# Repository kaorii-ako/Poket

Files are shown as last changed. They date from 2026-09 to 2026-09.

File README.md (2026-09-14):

# Poket

A pocket Bluetooth MP3 player built around an ESP32-S3.

Plays MP3s off a microSD card and sends them either to Bluetooth
headphones (A2DP source) or out a 3.5 mm jack.

> **Rev B changed the MCU.** The board started on an ESP32-S3, which turned out
> to have Bluetooth LE only — no BR/EDR — so A2DP could never have worked on it.
> `soc_caps.h` in ESP-IDF spells it out: the S3 defines `SOC_BLE_SUPPORTED` and
> not `SOC_BT_CLASSIC_SUPPORTED`. The classic ESP32 in the WROOM-32E-R2 has
> both, keeps its 2 MB PSRAM inside the chip package (so GPIO16/17 stay free,
> unlike a WROVER), and costs a USB-UART bridge because it has no native USB. 0.96" OLED, rotary
encoder, three transport buttons, LiPo with USB-C charging and a
coulomb-counting fuel gauge.

| | |
|---|---|
| MCU | ESP32-WROOM-32E-N16R2 (16 MB flash, 2 MB in-package PSRAM) |
| Storage | microSD over SPI |
| DAC | PCM5102A (I2S, internal PLL — no MCLK needed) |
| Headphone amp | PAM8908, charge-pump / ground-centred output |
| Charger | MCP73831, 500 mA, P-FET load share |
| Fuel gauge | BQ27441-G1 with 10 mΩ sense resistor |
| Rail | AP2112K-3.3, separate ferrite-isolated 3V3A for the audio |
| USB | CP2102N-A02 bridge + cross-coupled auto-reset (this part has no native USB) |
| Board | 80 × 54 mm, 4 layer (Sig / solid GND / Sig / Sig) |
| Case | 86 × 60 × 16.8 mm, 3D printed, two shells + slider cap, chamfered edges |

## The board

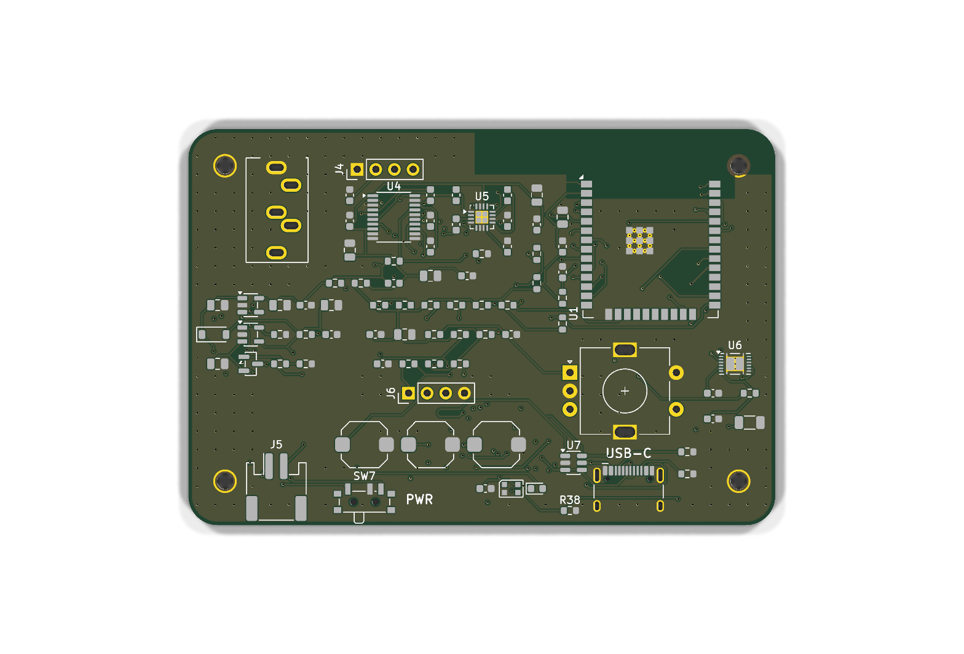
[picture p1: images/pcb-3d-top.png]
PCB top


Top side: ESP32-S3 module and its antenna keepout top-right, audio chain and
power block under where the OLED sits, encoder centre-right, three transport
buttons along the bottom, USB-C bottom-right, 3.5 mm jack top-left.

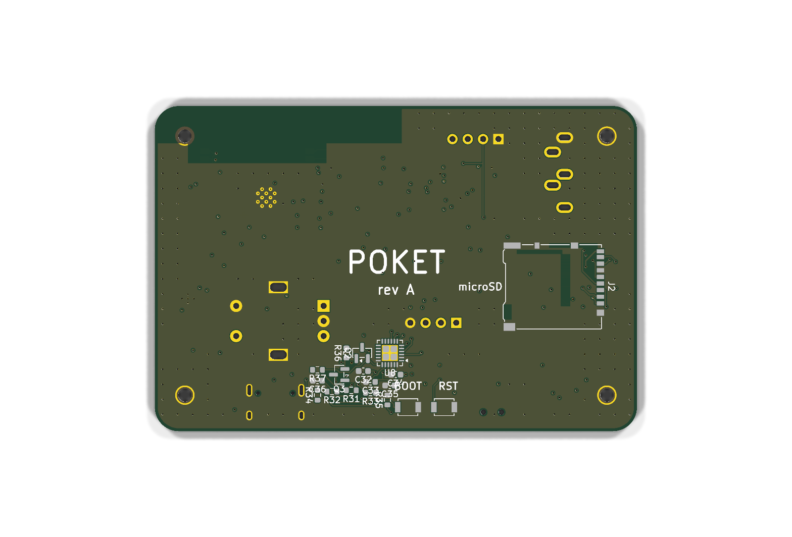
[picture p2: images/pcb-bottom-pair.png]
PCB bottom


Bottom side carries the microSD socket and the BOOT/RESET buttons, so the top
face stays clean. Right: all four copper layers together — In1.Cu is a solid
ground plane with no signal on it at all.

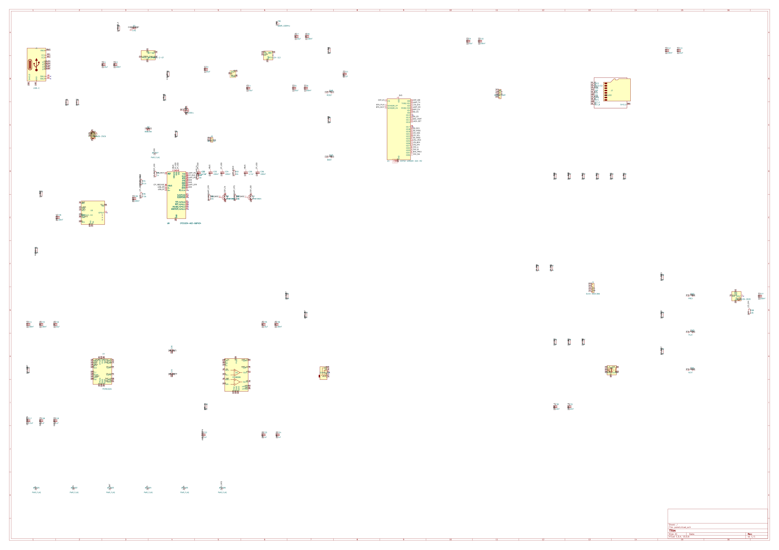
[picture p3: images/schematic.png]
schematic


Full schematic (also as a PDF: [`docs/poket-schematic.pdf`](docs/poket-schematic.pdf)).
ERC clean — 0 errors, 0 warnings.

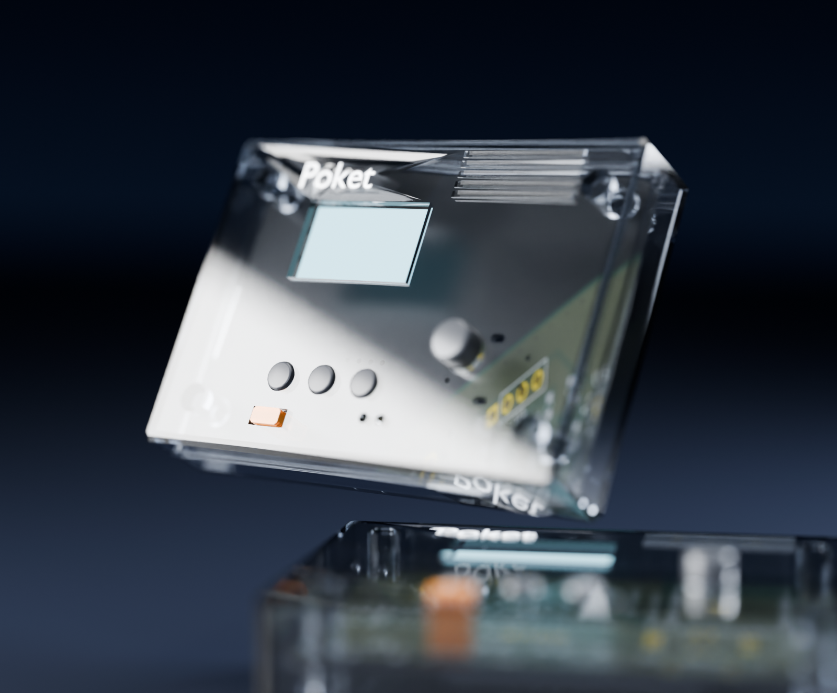
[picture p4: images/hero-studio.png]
case


## The firmware

ESP-IDF v5.3, C. Reads MP3s off the card with a vendored [minimp3], decodes
into PSRAM and pushes PCM to either sink — I2S to the PCM5102A, or A2DP source
to a paired pair of headphones.

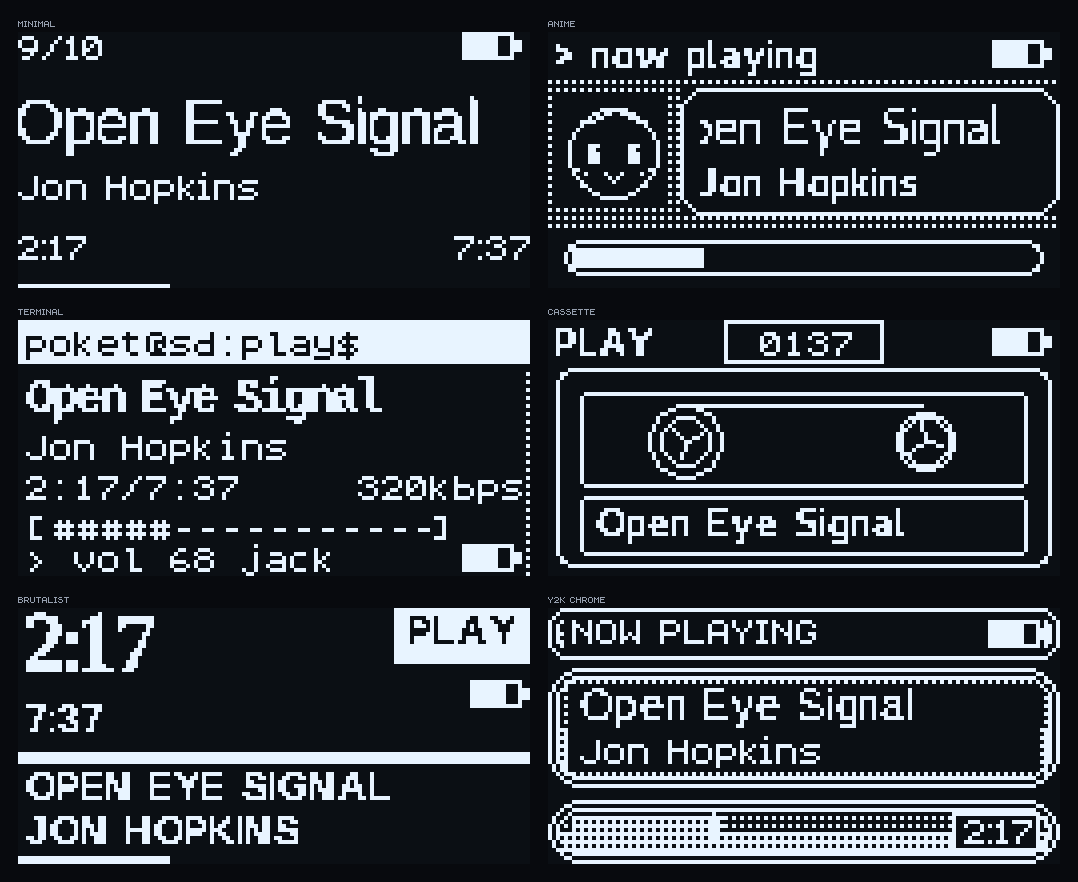
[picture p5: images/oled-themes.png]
OLED themes


Six themes ship, and they are not palette swaps — a 1-bit 128 x 64 panel has no
colour to vary, so each one earns its difference through layout, typeface,
iconography and motion. Clockwise from top-left: **Minimal**, **Anime**
(a face that blinks on its own timer), **Cassette** (reels that wind across as
the track plays), **Y2K Chrome**, **Brutalist**, **Terminal**. A seventh slot
takes a custom theme uploaded from the browser; that one is *data*, not code,
so an uploaded pack can lay out screens but can never execute on the device.

The two smallest faces are a hand-drawn 5x8 bitmap table
([`tools/font5x8.py`](firmware/tools/font5x8.py)) — rasterising an outline at
7-8 px loses whole stems, and a 1-bit panel has no antialiasing to hide that
with. The rest come from real faces through
[`tools/mkfont.py`](firmware/tools/mkfont.py).

### Build and flash

ESP-IDF v5.3, target `esp32`. Full detail in
[`firmware/README.md`](firmware/README.md).

```bash
. $HOME/esp/esp-idf/export.sh
cd firmware
idf.py set-target esp32          # once
idf.py build
idf.py -p /dev/ttyUSB0 flash monitor
```

`sdkconfig.defaults` carries the flash size, PSRAM, Classic Bluetooth and the
partition table, so a clean tree builds without menuconfig. The CP2102N bridge
handles reset and boot mode, so flashing needs no button presses; if auto-reset
ever fails, hold **BOOT**, tap **RESET**, release **BOOT**.

Then: put MP3s in `/Music` on a FAT32 card, power on, long-press the encoder,
join the `Poket-XXXX` network shown on screen and open **http://192.168.4.1**.

### The web app

Hold the encoder and Poket brings up its own Wi-Fi access point and serves a
page: drag MP3s onto it to write them to the card, browse the library, drive
transport, and pick the screen theme with a **live 128 x 64 preview**. The
preview is not an artist's impression — `web/proto/oled.js` is a port of
`ui/gfx.c` and runs the same theme code against the same generated glyph bytes,
painted at an integer zoom so one panel pixel is exactly N x N screen pixels
with smoothing off.

Four design directions are prototyped in
[`firmware/web/proto/`](firmware/web/proto/) — open `index.html`:

| | |
|---|---|
| `jcard.html` | ink on cassette card stock; upload zone is a blank Side B |
| `bench.html` | desk instrument — keycaps with travel, knurled knob, amber readout |
| `fab.html` | the board documenting itself: silkscreen on solder mask, designators, title block |
| `plain.html` | the canon settings page; the control the other three have to beat |

Wi-Fi and Bluetooth share one radio, so while the page is being served audio
routes out the 3.5 mm jack.

[minimp3]: firmware/components/minimp3/

## Video

| | |
|---|---|
| [`video/poket-promo.mp4`](video/poket-promo.mp4) | 22 s product film — five shots, titles |
| [`video/poket-assembly.mp4`](video/poket-assembly.mp4) | 6.5 s — parts drop in, then a turntable |

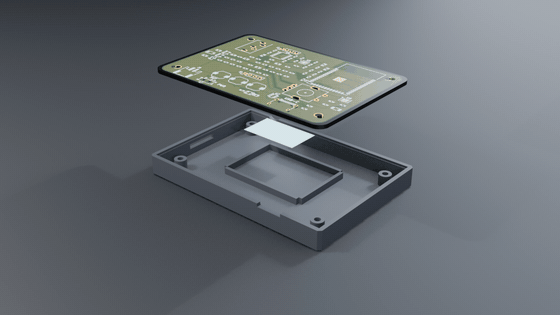
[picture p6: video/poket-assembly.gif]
assembly


Both are rendered from the same Blender scene, which rebuilds from scratch
with `blender/build_scene.py` (set `MODE` to `"promo"` or `"assembly"`).
Encode the PNG sequences with `tools/encode_video.sh`.

## Documentation

- [`docs/BOM.md`](docs/BOM.md) — bill of materials, ~$46/unit
- [`docs/ASSEMBLY.md`](docs/ASSEMBLY.md) — how to build one
- [`docs/DESIGN.md`](docs/DESIGN.md) — why each part was chosen, and the trade-offs
- [`docs/SUBMISSION.md`](docs/SUBMISSION.md) — what's done, what isn't
- [`JOURNAL.md`](JOURNAL.md) — build log

## Repo layout

```
poket.kicad_sch / .kicad_pcb / .kicad_pro   KiCad 10 project
firmware/                                   ESP-IDF app - drivers, audio, UI themes, web app
cad/enclosure.py                            parametric enclosure (FreeCAD, headless)
enclosure/*.step, *.stl                     exported case parts
docs/                                       BOM, assembly, design notes, schematic PDF
fab/                                        gerbers, drill, pick-and-place
images/                                     renders and screenshots
blender/                                    animation scene + board textures
video/                                      promo + assembly animations
tools/                                      fab export, video encode, PCB helper scripts
JOURNAL.md                                  build log
```

## Building the enclosure model

```
flatpak run --filesystem=host --command=FreeCADCmd org.freecad.FreeCAD cad/enclosure.py
```

Everything is driven by the constants at the top of `cad/enclosure.py`, so
if the PCB outline or a connector moves, change the number and re-run.

## Print settings

PETG or PLA, 0.2 mm layers, 4 perimeters, 20 % infill, no supports needed.
Front shell prints face-down, back shell prints tray-up. 4 × M2 heat-set
inserts (3.2 mm OD) in the front shell bosses; 4 × M2 × 12 screws from the
back.

## Status

**Hardware** — ERC **0 errors, 0 warnings**; DRC **0 errors, 0 schematic-parity
issues**, every signal net routed. The enclosure booleans against the real board
STEP with **0.0000 mm³** interference. Gerbers, drill and pick-and-place in
`fab/` are generated from this revision.

**Firmware** — complete and building. ESP-IDF v5.3, `idf.py build` succeeds from
a clean tree; `poket.bin` is 1.5 MB with 64 % of the app partition free. Drivers,
the audio path with A2DP linking, microSD over SPI, the library scanner, `.m3u`
playlists, the 1-bit graphics layer with six themes, the Wi-Fi access point, the
HTTP server and the web app are all in `firmware/`. Build and flash instructions:
[`firmware/README.md`](firmware/README.md).

**Not built.** No board has been fabricated, no part soldered, and no firmware
has ever run on hardware. Every image here is a render. The design is verified
in software and the firmware compiles — but "passes DRC and builds" and "works"
are different claims, and only the first is being made. Full gap list:
[`docs/SUBMISSION.md`](docs/SUBMISSION.md).

Three ground-pour fragments are untied, two of which carry a bypass capacitor's
ground. Documented rather than hidden.

## Design review

> **Not yet reviewed by another person.** This needs a second pair of eyes
> before fabrication, and nobody has given it one yet.
>
> When someone does, record it here: who reviewed it, when, what they flagged,
> and what changed as a result. An unreviewed board is a board with exactly one
> person's blind spots in it — and this project has already had one part choice
> that a reviewer would very likely have caught (the ESP32-S3 cannot do A2DP,
> which is the whole point of the device).

Worth a reviewer's attention in particular:

- **Power** — the MCP73831 charger, the DMG2301L load-share P-FET and the
  AP2112K rail, especially behaviour when USB and battery are both present.
- **The CP2102N block** — the 22.1 k/47.5 k VBUS sense divider and the
  cross-coupled auto-reset pair (`Q2` drives EN, `Q3` drives IO0, emitters
  cross). Both came from datasheets rather than from a copied schematic.
- **Strapping pins** — GPIO0, 2, 12 and 15. GPIO12 is deliberately left
  unconnected and the microSD runs on SPI to keep off it.
- **The antenna keepout** and whether the module is close enough to the board
  edge to radiate properly.

## License

MIT for code, CERN-OHL-S v2 for the hardware design files. See [`LICENSE`](LICENSE).

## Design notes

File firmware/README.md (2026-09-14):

# Poket firmware

ESP-IDF v5.3, target `esp32` (ESP32-WROOM-32E-N16R2).

```
main/
  main.c            bring-up order: NVS, panel, card, audio
  board.h           the pin map, extracted from the schematic netlist
  app/              the one shared state snapshot + the UI task
  drivers/          I2C, SSD1306, encoder + buttons, BQ27441 fuel gauge
  storage/          microSD over SPI, library scan, ID3, .m3u playlists
  audio/            minimp3 -> one sink interface -> I2S or A2DP
  ui/               1-bit graphics, six themes, font tables
  net/              Wi-Fi AP, HTTP server, the gzipped web app
web/                the web app source; build.py bundles it into net/www.h
tools/              font generation
```

## Build

Install ESP-IDF v5.3, then:

```bash
. $HOME/esp/esp-idf/export.sh      # wherever you installed it
cd firmware
idf.py set-target esp32            # only needed once
idf.py build
```

`sdkconfig.defaults` already carries everything that matters — 16 MB flash,
PSRAM, Classic Bluetooth with A2DP, the custom partition table — so a clean
tree builds without touching menuconfig.

Expect roughly:

```
poket.bin binary size 0x1741d0 bytes. Smallest app partition is 0x400000 bytes.
```

## Flash

The board has no native USB — a CP2102N bridge sits on UART0, with the usual
cross-coupled auto-reset pair — so flashing works without touching any buttons.

```bash
idf.py -p /dev/ttyUSB0 flash monitor
```

On Linux the port is usually `/dev/ttyUSB0`, on macOS
`/dev/cu.SLAB_USBtoUART`, on Windows a `COM` port. `idf.py -p PORT monitor`
alone opens the serial log; Ctrl-] exits.

If auto-reset ever fails, hold **BOOT**, tap **RESET**, release **BOOT**, and
flash again. Both buttons are on the back of the board.

Erasing everything, including the saved Wi-Fi password, theme choice and
remembered headset:

```bash
idf.py -p /dev/ttyUSB0 erase-flash
```

### Flashing prebuilt binaries

Without ESP-IDF installed, `esptool` is enough:

```bash
esptool.py --chip esp32 -p /dev/ttyUSB0 -b 460800 \
  --before default_reset --after hard_reset write_flash \
  --flash_mode dio --flash_size 16MB --flash_freq 80m \
  0x1000 build/bootloader/bootloader.bin \
  0x8000 build/partition_table/partition-table.bin \
  0x10000 build/poket.bin
```

## First run

1. Put MP3s in `/Music` on a FAT32 microSD card and insert it.
2. Power on. The splash shows while the library is scanned.
3. **Long-press the encoder** to start transfer mode. The screen shows the
   Wi-Fi name (`Poket-XXXX`) and its password — generated on first boot and
   kept in NVS, so it does not change.
4. Join that network and open **http://192.168.4.1**.

From the web app: drop MP3s in, search the library, make playlists, drive
transport, pick one of the six screen themes with a live preview, and link a
pair of Bluetooth headphones.

### Linking headphones

Poket is the A2DP **source**, so it goes looking rather than waiting to be
found. Put the headphones in pairing mode, hit **Scan for headphones**, and pick
them from the list. The headset is saved and reconnected automatically on later
boots. **Long-press Play** toggles between the jack and Bluetooth.

Wi-Fi and Bluetooth share one radio, so audio can stutter while the web app is
open. In normal use it is one or the other.

## Controls

| Input | Action |
|---|---|
| Encoder turn | volume, or move the selection in the browser |
| Encoder press | browser / now playing |
| Encoder long-press | start or stop transfer mode |
| Play | play / pause |
| Play long-press | switch between the jack and Bluetooth |
| Prev / Next | previous (restarts if >3 s in) / next |

## Regenerating the generated files

Both are checked in, so neither is needed for an ordinary build.

```bash
cd tools && ./genfonts.sh     # main/ui/fonts_gen.c and web/lib/fonts.js
cd web    && ./build.py       # bundles the web app into main/net/www.h
```

The web app is inlined and gzipped into rodata because the access point has no
route to the internet: a single external `<script>` would leave the page blank.
`build.py` fails the build if the bundle exceeds 60 kB gzipped, or if two
modules declare the same top-level name.

```bash
node web/lib/clock.test.mjs   # playback-position arithmetic
```

## Known gaps

Nothing here has run on real hardware — no board has been fabricated. It builds
and the logic follows Espressif's reference implementations, but it has never
played a note. See [`../docs/SUBMISSION.md`](../docs/SUBMISSION.md).

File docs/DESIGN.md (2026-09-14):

# Poket — design decisions and trade-offs

## What it is

An ESP32 Bluetooth MP3 player. Local MP3s on a microSD card, played
out either over Bluetooth A2DP (as a *source*, to headphones/speakers) or
through a wired 3.5 mm jack. 0.96" OLED, rotary encoder with push, three
transport buttons, single-cell LiPo with USB-C charging.

---

## Electrical

### MCU — ESP32-WROOM-32E-N16R2, not a bare chip
The module costs a few dollars more than the bare die plus flash plus
PSRAM, and it saves the antenna matching network, the RF layout review,
and a pile of risk on a first spin. 16 MB flash gives room for the
firmware and a filesystem; 2 MB in-package PSRAM gives the decode buffers you
want if you ever add gapless playback or a bigger UI.

Cost: the octal-PSRAM variant burns GPIO35/36/37 internally, so those are
off-limits. Native USB takes GPIO19/20. Everything else was assigned
around those.

### Audio chain — PCM5102A → PAM8908 → jack
The PCM5102A has an internal PLL, so it runs from BCK/LRCK alone and I
don't have to spend a GPIO and a clock domain on MCLK. Its output is
ground-centred thanks to an on-chip charge pump, which kills the usual
big DC-blocking electrolytics.

It can't drive 32 Ω headphones though (2.1 Vrms into 5 kΩ is a line
output), so the PAM8908 does the current. It's also a DirectDrive-style
charge-pump part — ground-referenced output, no output coupling caps, no
turn-on thump. Gain pins strapped for 0 dB; the amp is enabled from
GPIO21 so firmware can mute it before the DAC settles.

**Trade-off:** the PAM8908 is a QFN-16 with a thermal pad. Not
hand-solder friendly. If this were meant for hand assembly I'd have taken
the TPA6132A2 in the same pinout family, or dropped back to a jellybean
op-amp buffer and accepted the coupling caps.

### Fuel gauge — BQ27441-G1, not the MAX17048 I wanted
The MAX17048 is the nicer part for this job: ModelGauge estimates state of
charge from voltage alone, so there's no sense resistor and no
interruption of the pack ground. But there's no symbol for it in the
stock KiCad libraries and I wasn't confident enough in the TDFN pinout
from memory to draw one — a wrong pin here is a dead board.

The BQ27441-G1 has a verified KiCad symbol, so that's what went in. It's
a real coulomb counter, which is arguably *more* accurate, at the cost of
a 10 mΩ sense resistor in series with the pack negative and a slightly
more careful ground layout (SRP on the battery side, SRN on system
ground).

### Power path
```
USB-C ──┬── USBLC6 ESD ── D+/D- ── CP2102N ── UART0 ── ESP32
        ├── MCP73831 (500 mA) ── VBAT ── LiPo
        └── Schottky ──┐
                       ├── VSYS ── slide switch on LDO EN ── AP2112K-3.3 ── 3V3
   VBAT ── P-FET ──────┘                                                    │
          (off when VBUS present)                                    ferrite ┴ 3V3A
```

Two decisions worth calling out:

**Load-share gate divider.** First pass used 100 k / 100 k from VBUS to
the P-FET gate. That puts the gate at 2.5 V while the source sits at
4.2 V — Vgs = −1.7 V, so the FET is *partially on* and the USB supply
back-feeds the battery through it. Changed to 10 k from VBUS to the gate
and a 1 M pulldown: gate sits at ~5 V with USB in (hard off) and at 0 V
without it (hard on).

**LDO, not a buck-boost.** A TPS63020 would hold 3.3 V down to a 3.0 V
cell and be ~90 % efficient instead of ~80 %. An AP2112K is a $0.10
SOT-23-5 and a basic JLC part. For a first build I took the simple one and
accepted that the usable cell range stops around 3.4 V. The board will
run below that (the ESP32 and both audio parts are happy at 3.0 V),
the rail just isn't regulated any more.

**Analog rail.** 3V3A is split off through a ferrite bead with its own
bulk + bypass, feeding the DAC and amp only. Cheap insurance against the
radio and the SD card putting hash into the audio.

### microSD on SPI, not SPI
Four data lines instead of one, roughly 4× the read bandwidth for the
same clock. MP3 doesn't need it, but it means the card is idle more of
the time, which matters when the radio is also asking for the bus. 10 k
pull-ups on CMD and all four data lines; card detect on the socket's
detect switch.

### Board stackup — 4 layer
Signal / **solid GND** / signal+GND pour / signal+GND pour.

The first autorouting pass came back with 439 mm of signal trace sitting
on In1.Cu, which shreds exactly the plane I added the layer for. Second
pass I marked In1.Cu as `(type power)` in the Specctra DSN so the router
would not touch it — it now carries no signal copper at all, so every
trace on the component side has an uninterrupted return path directly
underneath it. In2.Cu and B.Cu carry the rest of the routing with ground
poured around them.

### The ESP32 antenna keepout
KiCad's `ESP32-WROOM-32E-N16R2` footprint carries a 48 × 21 mm copper keepout
zone for the antenna, applied to every layer, plus a courtyard outline of
the same shape. Both are far more conservative than the module datasheet
needs and they make placement on an 80 × 54 board impossible.

I removed the vendor zone from the board instance, replaced the courtyard
with a plain rectangle around the module body, and shaped all four ground
pours to leave a notch (x 52–74, y 0–9.5 mm) open under and beside the
antenna instead. Same intent, sized to the part.

---

## Mechanical

### Layout logic
The front face is what you look at, so the screen, buttons and knob are
all top-side. Two things went to the *bottom* of the board on purpose:

- **microSD socket** — it's 15 mm deep. On the top side it would have
  eaten a fifth of the usable area; underneath, it tucks into the space
  above the battery and its slot lines up with the left wall.
- **BOOT and RESET** — these are setup buttons, not user controls.
  Pinholes in the back shell instead of two extra holes in the face.

### Case
86 × 60 × 16.8 mm, two shells split 1 mm above the PCB plane.

- **Back shell** is a tray: 1.5 mm floor, four 4.7 mm posts that the PCB
  sits on, and ribs that pen the battery into a 37 × 26 mm pocket so it
  can't slide onto the BOOT/RESET pinholes.
- **Front shell** is the cover, with the display window, three button
  holes, the encoder shaft hole, two LED pinholes, the power-slider slot,
  and five debossed vent slots top-right that are purely decoration.
- **Registration** is a 0.7 mm tongue on the front shell dropping into a
  0.25 mm-clearance rebate in the back shell wall.
- **Fastening** is four M2 × 12 screws from the back, through the posts
  and the PCB, into heat-set inserts in the front shell bosses. One screw
  does all three jobs.

### The slider cap
The power switch is an SMD slide switch whose actuator only stands about
2.5 mm off the PCB, but the front face is 7.5 mm above it — you'd never
reach it. So there's a third printed part: a 6 × 3 × 8.8 mm cap with a
pocket that grips the actuator and thumb grooves on top, poking through a
7.6 mm slot. 1.6 mm of travel, which matches the switch.

### Assumptions
- FDM print, PETG or PLA, 0.2 mm layers, 0.2 mm part clearance
- M2 heat-set inserts, 3.2 mm OD × 4 mm
- 402535-size LiPo (4 × 25 × 35 mm, ~400 mAh) in the battery bay
- 0.96" I2C SSD1306 module, 27.3 × 27.8 mm, on a 4-pin header

---

## Known compromises

1. **Screw near the antenna.** The top-right mounting hole is ~3 mm from
   the module's antenna edge. It's an unplated hole with no copper, but a
   steel M2 screw there isn't ideal. Moving it means an asymmetric screw
   pattern; I took the symmetry.
2. **No MCLK to the DAC.** Fine for the PCM5102A's internal PLL, but it
   rules out swapping in a DAC that needs a master clock without a board
   change.
3. **LDO efficiency.** See above — costs maybe 15 % of runtime versus a
   buck-boost.
4. **Screen is left of centre** on the front face, because the OLED
   module hangs off a header at a fixed spot. Reads as deliberate
   asymmetry (screen left, knob right) rather than a mistake, but it
   wasn't a free choice.
5. **QFN parts.** The amp and the fuel gauge both need reflow or a hot
   plate. This board wants to be assembled, not hand-built.

## Why the MCU changed (Rev A -> Rev B)

Rev A used an ESP32-S3. It cannot do A2DP: the S3 has Bluetooth LE only, no
BR/EDR. ESP-IDF's own capability header says so —

```
soc/esp32/include/soc/soc_caps.h    #define SOC_BT_CLASSIC_SUPPORTED (1)
soc/esp32s3/include/soc/soc_caps.h  #define SOC_BLE_SUPPORTED        (1)   <- only
```

`CONFIG_BT_CLASSIC_ENABLED` is not even a config symbol for that target. Sending
audio to Bluetooth headphones is the entire point of this device, so the part
had to change.

**ESP32-WROOM-32E-N16R2** (ESP32-D0WDR2-V3): Classic BT + BLE, 16 MB flash, and
2 MB of PSRAM *inside the chip package* — so, unlike a WROVER, it costs only
GPIO16 rather than GPIO16 and GPIO17.

What that dragged in:

| Change | Why |
|---|---|
| CP2102N-A02 USB-UART bridge | the classic ESP32 has no native USB |
| 22.1k/47.5k divider on the bridge's VBUS pin | datasheet: abs max on that pin is VIO + 2.5 V |
| 1k pull-up on RSTb to VIO | datasheet value; 10k is not enough |
| 4.7 uF + 0.1 uF at each bridge power pin | datasheet, per pin, not per chip |
| Cross-coupled auto-reset pair | Espressif's DevKitC truth table: asserting DTR and RTS together must *not* reset, because opening a serial port does exactly that |
| microSD moved to SPI | the 4-bit slot puts DAT2 on GPIO12/MTDI, the flash-voltage strap; a card's pull-up there tells the bootloader the flash is 1.8 V and bricks the boot |
| Battery-sense divider deleted | ADC1 is fully used by the encoder and the input-only buttons, ADC2 stops working with Wi-Fi up, and the BQ27441 reports voltage over I2C anyway |
| 10k pull-down on GPIO2 | download-mode strap, and a WS2812 data pin is high-Z |

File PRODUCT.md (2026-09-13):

# Poket — product context

> Written from the maintainer's explicit brief (the four scoping answers on the
> firmware request) rather than a fresh interview. Anything not covered by that
> brief is marked **[assumed]** and should be corrected rather than trusted.

## What it is

A pocket MP3 player built from scratch: custom 4-layer PCB around an
ESP32-S3-WROOM-1, 3D-printed case, microSD library, 0.96" mono OLED, rotary
encoder and three transport buttons. Audio leaves either over Bluetooth A2DP
to headphones or out a 3.5 mm jack.

It is a hardware project first. The web app exists because the device has no
other way to receive files.

## Who uses it

One person: whoever built the unit. There is no fleet, no accounts, no
multi-tenant anything. **[assumed]** they are technically confident — they
soldered a QFN — but are using this on a phone, one-handed, while the device
sits on a desk.

## The web app's job

The device has no keyboard, no file manager, and a 128×64 screen. Everything
that is painful on that screen moves to the browser:

1. **Get MP3s onto the card.** The primary job. Drag, drop, done.
2. **Browse and organise** what is already there; build playlists.
3. **Choose the OLED theme**, with a preview accurate enough to decide from.
4. **Drive playback** from the browser while the device is across the room.
5. **Settings** — Wi-Fi, Bluetooth pairing, sleep, brightness, battery.

## Hard constraints that shape the design

- **Served off an ESP32-S3.** The whole app — markup, styles, script — is
  embedded in flash and gzipped. Budget: **under 60 kB compressed, single
  file, zero network dependencies.** No framework, no CDN font, no icon
  package. This is the constraint that decides the most.
- **Wi-Fi and Bluetooth share one radio.** When the web app is reachable,
  Bluetooth audio is not. Transfer mode and playback mode are genuinely
  exclusive and the UI has to be honest about that rather than hide it.
- **Uploads are slow.** ~1–2 MB/s over the device's own AP. A 60 MB album is
  most of a minute. Progress has to be real, per-file, and resumable in the
  sense that a failure names the file that failed.
- **The device may be on battery.** Long transfers matter; the UI should show
  charge state without being asked.
- **One client at a time, realistically.** No collaboration, no conflict
  resolution, no optimistic concurrency.

## What success looks like

Someone plugs in a fresh card, joins the Poket hotspot, drags a folder of
music in, picks a theme, and unplugs — without reading anything.

## Explicitly out of scope

Accounts, cloud sync, streaming services, transcoding, album art fetching,
mobile apps, OTA firmware from the browser **[assumed]** — the partition table
reserves OTA slots but nothing in the brief asked for browser-driven updates.

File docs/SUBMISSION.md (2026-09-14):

# Submission checklist

## What's in the repo

| Requirement | Where | Status |
|---|---|---|
| Devlog / journal | [`JOURNAL.md`](../JOURNAL.md) | 11 entries, ~34 h, written as the work happened |
| Schematic (source) | `poket.kicad_sch` | KiCad 10, ERC **0 errors, 0 warnings** |
| Schematic (PDF / PNG) | [`docs/poket-schematic.pdf`](poket-schematic.pdf), `images/schematic.png` | regenerated from the Rev B board |
| PCB layout (source) | `poket.kicad_pcb` | DRC **0 errors, 0 schematic-parity issues**, every signal net routed |
| Gerbers + drill | `fab/poket-gerbers.zip` | 4-layer, JLCPCB-ready, Rev B |
| Pick-and-place | `fab/poket-pos.csv` | Rev B |
| BOM with costs | [`docs/BOM.md`](BOM.md), [`docs/BOM.csv`](BOM.csv) | costs are **estimates**; supplier P/Ns not filled in |
| CAD source | `cad/enclosure.py` | parametric, rebuilds from the script |
| Printable files | `enclosure/*.stl` | 3 parts, all single valid solids, 0.0000 mm³ interference vs the board |
| Renders / video | `images/`, `video/` | board renders regenerated for Rev B |
| License | [`LICENSE`](../LICENSE) | MIT (code) + CERN-OHL-S v2 (hardware) |
| Assembly instructions | [`docs/ASSEMBLY.md`](ASSEMBLY.md) | includes the Rev B parts |
| **Firmware** | `firmware/` | **written and building** — ESP-IDF v5.3, `poket.bin` 1.5 MB, 64 % of the app partition free |
| Flashing instructions | [`firmware/README.md`](../firmware/README.md), README | build, flash, first run, controls |
| Design reviewed by another person | — | **not yet done** — see the README's Design review section |
| Photos of real hardware | — | **never built** |

## The firmware

ESP-IDF v5.3, target `esp32`. `idf.py build` succeeds from a clean tree.

- **Audio** — vendored minimp3, one sink interface behind I2S (PCM5102A) and
  A2DP source. Bluetooth linking is implemented properly: inquiry, Class-of-
  Device filter for audio sinks, connect, then `CHECK_SRC_RDY` → `MEDIA_CTRL_START`.
  The headset is remembered in NVS and reconnected at boot.
- **Storage** — microSD over SPI, library scan, ID3 tags, playlists as `.m3u`
  files in `/Music/Playlists` so any other player can read them.
- **UI** — 1-bit graphics layer and six themes that differ in layout, type,
  iconography and motion, because a 1-bit panel has no colour to vary. Custom
  theme packs are interpreted as *data*, never executed.
- **Web app** — served gzipped from rodata, 30 kB, no external requests. Upload,
  library with search, playlists, transport, shuffle/repeat, Bluetooth pairing,
  and a live 128×64 screen preview that runs the firmware's own drawing code
  against the same glyph bytes.

## Honest gaps

**1. Nothing has been physically built.** Every image is a render. No board has
been fabricated, no part soldered, no measurement taken, and no firmware has
ever run on hardware. The design is ERC/DRC-clean, the enclosure is
boolean-verified against the real board outline, and the firmware compiles — but
"it passes DRC and builds" and "it works" are very different claims, and only
the first is being made here.

**2. Three ground-pour fragments are untied.** Two of them carry a bypass
capacitor's ground (C19, C33). The plane itself is intact and every signal net
is routed, but those two caps' ground return is not ideal. The fix is to move
the caps and re-route; noted rather than hidden.

**3. The BOM has no supplier part numbers.** Manufacturer part numbers are real
and chosen deliberately; LCSC/DigiKey numbers are blank rather than guessed.

**4. Prices are estimates**, not quotes. ~$46 is the right order of magnitude.

**5. Nobody else has reviewed it.** A second pair of eyes before fabrication is
the cheapest bug-finding there is, and this design has not had one. The README
lists what a reviewer should look at hardest.

**6. Rev A was wrong about Bluetooth.** The first board used an ESP32-S3, which
has Bluetooth LE only and physically cannot do A2DP. That is documented in
[`DESIGN.md`](DESIGN.md) and in the devlog rather than quietly corrected — it is
the most useful thing I learned building this.

## Is it ready?

As a **design and firmware submission**: yes, with one caveat — it has not been
reviewed by another person, which is worth doing before anyone spends money
having it made.

On the substance: Schematic, layout, fabrication
outputs, enclosure, and a complete firmware source tree that builds, all
consistent with each other and all regenerated from the current revision.

As a **working device**: no, and it does not claim to be. It has never been
built. Everything above describes what the design and the code do, not what a
physical unit has been observed to do.

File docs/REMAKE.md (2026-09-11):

# Shot-for-shot remake of the reference film

`video/poket-remake.mp4` is a beat-for-beat rebuild of the reference phone
launch film, with Poket in place of the phone.

## How the cut list was derived

Not by eye — ffmpeg scene detection on the source:

```
ffmpeg -i reference.mp4 -filter:v "select='gt(scene,0.30)',showinfo" -f null -
```

That gives 16 cuts. The last four shots (34.36 s onward) are a live-action
talking head at a desk. There is no way to reproduce those here, so the remake
covers the 13 CG shots, 0 → 34.36 s, at the source's own 25 fps and 1280 × 720,
with the same durations and the same cut rhythm.

| # | in | out | source shot | Poket equivalent |
|---|---|---|---|---|
| 1 | 0.00 | 3.24 | wide, product tiny, drifting | same, edge-on |
| 2 | 3.24 | 6.64 | macro along the top edge | chamfer + vent grille |
| 3 | 6.64 | 10.04 | dark, red accent, lens macro | dark, red kicker across the slider |
| 4 | 10.04 | 13.32 | front on, screen lit | same, stood upright |
| 5 | 13.32 | 17.56 | back detail → fanned array | board through the case → array of six |
| 6 | 17.56 | 19.84 | thin side profile | stood on its long edge |
| 7 | 19.84 | 22.56 | macro of the back panel | PCB through the back shell |
| 8 | 22.56 | 23.36 | top-edge module macro | 3.5 mm jack corner |
| 9 | 23.36 | 24.28 | extreme lens macro | encoder knob |
| 10 | 24.28 | 24.64 | fast cut, lenses + red square | buttons + orange slider |
| 11 | 24.64 | 26.36 | back edge, charging coil | back edge, microSD slot |
| 12 | 26.36 | 31.44 | three-quarter back, rotating | same |
| 13 | 31.44 | 34.36 | wide, rotates to front | same |

## Two things that needed solving

**The macro shots kept missing.** With one continuous tumble under the whole
film, a camera aimed at a fixed world point framed empty space by the time the
shot arrived. Fixed by parenting the macro cameras *to the unit* so they ride
it, and setting the unit's pose explicitly at every cut instead of letting one
rotation run through.

**Translucent shells eat macro depth of field.** At 100 mm and f/2.8 from 5 cm,
the out-of-focus near surface of the shell filled the frame and the subject
behind it never read. The macros now sit 8–12 cm out at f/8–f/11.

## Rebuilding

`blender/build_remake.py` constructs the whole thing from the STLs — it chains
through `build_hero.py` for the unit, engraving and translucent material.
Render the sequence, then:

```
ffmpeg -framerate 25 -i blender/remake/r_%04d.png -c:v libx264 \
       -pix_fmt yuv420p -crf 18 -preset slow video/poket-remake.mp4
```

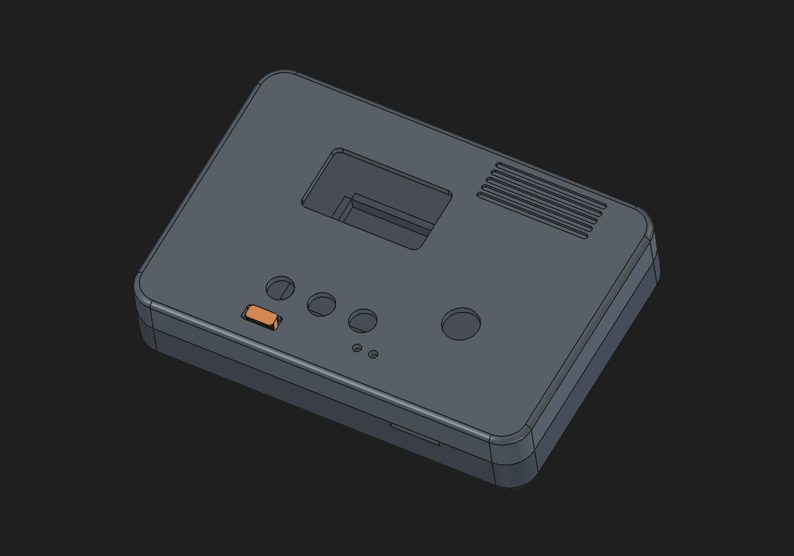
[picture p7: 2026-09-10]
images/case-front-face.png

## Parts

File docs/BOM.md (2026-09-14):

# Poket — bill of materials

98 parts across 41 line items. Machine-readable version: [`BOM.csv`](BOM.csv).

> **Prices are ballpark estimates, not quotes.** They're single-unit hobby
> pricing from memory, good enough to size the project, wrong enough that you
> should re-check every line before ordering. The **supplier part number column
> is deliberately empty** — I'm not going to invent LCSC `C` numbers, because a
> wrong one means you get the wrong part in the post. Search the MPN on
> LCSC/DigiKey/Mouser, confirm the package matches the Package column, and fill
> them in as you go.

## Cost summary

| | Est. |
|---|---|
| Electronics + modules | **$24.13** |
| PCB, screws, inserts, filament | **$21.60** |
| **Total for one unit** | **≈ $46** |

The PCB dominates the second line — JLCPCB's 4-layer minimum is 5 boards, so
per-board cost drops hard if you build more than one. Boards 2–5 cost roughly
$25 each in parts alone.

## Semiconductors

| Ref | Qty | Part | Package | What it does |
|---|---|---|---|---|
| U1 | 1 | ESP32-WROOM-32E-N16R2 | SMD module | MCU + Bluetooth radio. 16 MB flash, 2 MB in-package PSRAM. **Classic BT (BR/EDR) — the S3 has BLE only and cannot do A2DP** |
| U4 | 1 | PCM5102APWR | TSSOP-20 | I2S stereo DAC. Internal PLL, so no MCLK line needed |
| U5 | 1 | PAM8908JER | QFN-16 3×3 EP | Headphone amp. Charge pump gives ground-centred output — no DC blocking caps |
| U6 | 1 | BQ27441DRZR-G1A | SON-12 2×4 mm | Coulomb-counting fuel gauge, I2C |
| U2 | 1 | MCP73831T-2ACI/OT | SOT-23-5 | LiPo charger, 500 mA set by R3 |
| U3 | 1 | AP2112K-3.3TRG1 | SOT-23-5 | 3.3 V 600 mA LDO with enable |
| U7 | 1 | USBLC6-2SC6 | SOT-23-6 | USB ESD protection |
| U8 | 1 | CP2102N-A02-GQFN24 | QFN-24 4×4 | USB-UART bridge. The classic ESP32 has no native USB |
| Q2, Q3 | 2 | MMBT3904 | SOT-23 | Auto-reset pair, cross-coupled off DTR/RTS |
| Q1 | 1 | DMG2301L | SOT-23 | P-FET load-share switch |
| D3 | 1 | B5819WS | SOD-123 | Schottky, USB→VSYS |
| D1 | 1 | WS2812B-2020 | PLCC-4 2×2 mm | Addressable status LED |
| D2 | 1 | KT-0603G or equiv. | 0603 | Charge indicator |

**Two parts need reflow or a hot plate** — U5 (QFN with a thermal pad) and U6
(SON-12 at 0.4 mm pitch). This board wants to be assembled, not hand-built.

## Connectors, switches, display

| Ref | Qty | Part | Notes |
|---|---|---|---|
| J1 | 1 | HC-TYPE-C-16P-01A | USB-C receptacle, USB 2.0 |
| J2 | 1 | DM3AT-SF-PEJM5 | microSD, push-push, with card detect. **Mounted on the underside** |
| J3 | 1 | SJ1-3535NG | 3.5 mm jack, switched tip for plug detect |
| J5 | 1 | S2B-PH-SM4-TB | JST-PH battery connector |
| J4, J6 | 2 | 1×4 header 2.54 mm | OLED, UART debug |
| SW1 | 1 | EC11E, 20 mm shaft | Rotary encoder with push |
| SW2–4 | 3 | 6×6×5 mm tact | Prev / play / next |
| SW5–6 | 2 | B3U-1000P | BOOT / RESET, **underside**, reached through back-shell pinholes |
| SW7 | 1 | PCM12SMTR | Power slide switch — drives the LDO enable, not the battery current |
| DS1 | 1 | SSD1306 0.96" I2C, 128×64 | 27.3 × 27.8 mm module, 4-pin |
| BT1 | 1 | LiPo 402535, ~400 mAh | 4 × 25 × 35 mm. **Must have protection circuitry** |

## Passives

All 0603 unless noted. 1 % resistors, X7R/X5R ceramics.

| Value | Qty | Refs |
|---|---|---|
| 10 µF 0805 16 V | 9 | C1, C3–C5, C7, C9, C13, C16, C25 |
| 1 µF | 8 | C11, C18–C24 |
| 100 nF | 11 | C2, C6, C8, C10, C12, C14, C15, C26–C29 |
| 2.2 µF | 1 | C17 (DAC charge-pump flying cap) |
| 10 nF | 2 | C30, C31 (encoder RC) |
| 10 k | 18 | R5, R7, R8, R11–R19, R25–R30 |
| 100 k | 3 | R20–R22 |
| 5.1 k | 2 | R1, R2 (USB-C CC pulldowns — **both required**) |
| 4.7 k | 2 | R9, R10 (I2C) |
| 2 k | 1 | R3 (sets 500 mA charge current) |
| 1 k | 2 | R4, R23 |
| 1 M | 1 | R6 |
| 0.01 Ω 1206 1 W | 1 | R24 (fuel-gauge sense — **not a generic 0 Ω**) |
| 600 Ω @ 100 MHz bead | 1 | FB1 (isolates the 3V3A analog rail) |

## Fabrication and hardware

| Item | Qty | Spec |
|---|---|---|
| PCB | 5 (min order) | 80 × 54 mm, **4 layer**, 1.6 mm, HASL or ENIG |
| Heat-set inserts | 4 | M2 × 4 mm, 3.2 mm OD |
| Screws | 4 | M2 × 12 mm pan head |
| Filament | ~25 g | PETG or PLA |

### PCB order settings (JLCPCB)

| | |
|---|---|
| Layers | 4 |
| Dimensions | 80 × 54 mm |
| Thickness | 1.6 mm |
| Min track / clearance used | 0.20 mm / 0.15 mm |
| Min drill used | 0.20 mm |
| Impedance control | not required |

Upload `fab/poket-gerbers.zip`. The design uses nothing outside JLCPCB's
standard 4-layer capability (they do 0.127 mm track/space and 0.15 mm drill).

### Print settings

PETG or PLA, 0.2 mm layers, 4 perimeters, 20 % infill, **no supports needed**.
Front shell prints face-down, back shell tray-up, slider cap on its side.

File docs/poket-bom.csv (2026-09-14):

Reference | Value | Footprint | QUANTITY
C1,C3-C5,C7,C9,C13,C16,C25 | 10uF | Capacitor_SMD:C_0805_2012Metric | 9
C2,C6,C8,C10,C12,C14,C15,C26-C29,C33,C34,C36 | 100nF | Capacitor_SMD:C_0603_1608Metric | 14
C11,C18-C24 | 1uF | Capacitor_SMD:C_0603_1608Metric | 8
C17 | 2.2uF | Capacitor_SMD:C_0603_1608Metric | 1
C30,C31 | 10nF | Capacitor_SMD:C_0603_1608Metric | 2
C32,C35 | 4.7uF | Capacitor_SMD:C_0603_1608Metric | 2
D1 | WS2812B-2020 | LED_SMD:LED_WS2812B-2020_PLCC4_2.0x2.0mm | 1
D2 | CHG | LED_SMD:LED_0603_1608Metric | 1
D3 | B5819W | Diode_SMD:D_SOD-123 | 1
FB1 | 600R_100MHz | Inductor_SMD:L_0603_1608Metric | 1
J1 | USB-C | Connector_USB:USB_C_Receptacle_HCTL_HC-TYPE-C-16P-01A | 1
J2 | microSD | Connector_Card:microSD_HC_Hirose_DM3AT-SF-PEJM5 | 1
J3 | 3.5mm_TRS | Connector_Audio:Jack_3.5mm_CUI_SJ1-3535NG_Horizontal | 1
J4 | OLED-SSD1306 | Connector_PinHeader_2.54mm:PinHeader_1x04_P2.54mm_Vertical | 1
J5 | BATT-JST | Connector_JST:JST_PH_S2B-PH-SM4-TB_1x02-1MP_P2.00mm_Horizontal | 1
J6 | DEBUG-UART | Connector_PinHeader_2.54mm:PinHeader_1x04_P2.54mm_Vertical | 1
Q1 | DMG2301L | Package_TO_SOT_SMD:SOT-23 | 1
Q2,Q3 | MMBT3904 | Package_TO_SOT_SMD:SOT-23 | 2
R1,R2 | 5.1k | Resistor_SMD:R_0603_1608Metric | 2
R3 | 2k | Resistor_SMD:R_0603_1608Metric | 1
R4,R23,R31,R32 | 1k | Resistor_SMD:R_0603_1608Metric | 4
R5,R7,R8,R11-R19,R25-R30,R33,R36-R38 | 10k | Resistor_SMD:R_0603_1608Metric | 22
R6 | 1M | Resistor_SMD:R_0603_1608Metric | 1
R9,R10 | 4.7k | Resistor_SMD:R_0603_1608Metric | 2
R20 | 100k | Resistor_SMD:R_0603_1608Metric | 1
R24 | 0.01 | Resistor_SMD:R_1206_3216Metric | 1
R34 | 22.1k | Resistor_SMD:R_0603_1608Metric | 1
R35 | 47.5k | Resistor_SMD:R_0603_1608Metric | 1
SW1 | EC11E-Switch | Rotary_Encoder:RotaryEncoder_Alps_EC11E-Switch_Vertical_H20mm | 1
SW2 | PREV | Button_Switch_SMD:SW_Push_1TS009xxxx-xxxx-xxxx_6x6x5mm | 1
SW3 | PLAY | Button_Switch_SMD:SW_Push_1TS009xxxx-xxxx-xxxx_6x6x5mm | 1
SW4 | NEXT | Button_Switch_SMD:SW_Push_1TS009xxxx-xxxx-xxxx_6x6x5mm | 1
SW5 | BOOT | Button_Switch_SMD:SW_SPST_B3U-1000P | 1
SW6 | RESET | Button_Switch_SMD:SW_SPST_B3U-1000P | 1
SW7 | PWR | Button_Switch_SMD:SW_SPDT_PCM12 | 1
U1 | ESP32-WROOM-32E-R2 | RF_Module:ESP32-WROOM-32E | 1
U2 | MCP73831-2-OT | Package_TO_SOT_SMD:SOT-23-5 | 1
U3 | AP2112K-3.3 | Package_TO_SOT_SMD:SOT-23-5 | 1
U4 | PCM5102A | Package_SO:TSSOP-20_4.4x6.5mm_P0.65mm | 1
U5 | PAM8908 | Package_DFN_QFN:QFN-16-1EP_3x3mm_P0.5mm_EP1.7x1.7mm | 1
U6 | BQ27441-G1 | Package_SON:Texas_S-PDSO-N12 | 1
U7 | USBLC6-2SC6 | Package_TO_SOT_SMD:SOT-23-6 | 1
U8 | CP2102N-A02-GQFN24 | Package_DFN_QFN:QFN-24-1EP_4x4mm_P0.5mm_EP2.6x2.6mm | 1

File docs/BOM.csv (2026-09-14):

Section | Ref | Qty | Value | MPN | Package | Description | Est unit USD | Est ext USD
MCU | U1 | 1 | ESP32-WROOM-32E-N16R2 | ESP32-WROOM-32E-N16R2 | SMD module | Dual-core MCU + Classic BT/BLE/WiFi radio 16MB flash 2MB in-package PSRAM | 3.80 | 3.80
Audio | U4 | 1 | PCM5102A | PCM5102APWR | TSSOP-20 | I2S stereo DAC internal PLL no MCLK needed | 2.20 | 2.20
Audio | U5 | 1 | PAM8908 | PAM8908JER | QFN-16 3x3 EP | Stereo headphone amp charge-pump ground-centred output | 0.60 | 0.60
Audio | J3 | 1 | 3.5mm TRS | SJ1-3535NG | THT horizontal | 3.5mm stereo jack with switched tip for plug detect | 0.60 | 0.60
Power | U2 | 1 | MCP73831-2-OT | MCP73831T-2ACI/OT | SOT-23-5 | Single-cell LiPo charger 500mA set by R3 | 0.65 | 0.65
Power | U3 | 1 | AP2112K-3.3 | AP2112K-3.3TRG1 | SOT-23-5 | 3.3V 600mA LDO with enable | 0.20 | 0.20
Power | U6 | 1 | BQ27441-G1 | BQ27441DRZR-G1A | SON-12 2x4mm | Coulomb-counting fuel gauge I2C | 2.80 | 2.80
Power | Q1 | 1 | DMG2301L | DMG2301L | SOT-23 | P-channel MOSFET load-share switch | 0.20 | 0.20
Power | D3 | 1 | B5819W | B5819WS | SOD-123 | Schottky diode USB-to-VSYS path | 0.05 | 0.05
Power | U7 | 1 | USBLC6-2SC6 | USBLC6-2SC6 | SOT-23-6 | USB ESD protection array | 0.25 | 0.25
Storage | J2 | 1 | microSD | DM3AT-SF-PEJM5 | SMD push-push | microSD socket with card-detect switch | 1.00 | 1.00
UI | SW1 | 1 | EC11E | EC11E15244A3 | THT vertical H20mm | Rotary encoder with push switch | 0.45 | 0.45
UI | SW2-SW4 | 3 | Tact 6x6x5 | TS-1187A-B-A-B | SMD 6x6x5mm | Transport buttons prev/play/next | 0.10 | 0.30
UI | SW5-SW6 | 2 | Tact 3.9x2.9 | B3U-1000P | SMD | BOOT and RESET on the underside | 0.15 | 0.30
UI | SW7 | 1 | Slide SPDT | PCM12SMTR | SMD | Power slide switch drives the LDO enable | 0.30 | 0.30
UI | D1 | 1 | WS2812B-2020 | WS2812B-2020 | PLCC-4 2x2mm | Addressable RGB status LED | 0.15 | 0.15
UI | D2 | 1 | LED green | KT-0603G | 0603 | Charge status LED | 0.03 | 0.03
Connectors | J1 | 1 | USB-C | HC-TYPE-C-16P-01A | SMD 16P | USB-C receptacle USB 2.0 | 0.30 | 0.30
Connectors | J5 | 1 | JST-PH 2pin | S2B-PH-SM4-TB | SMD horizontal | Battery connector | 0.15 | 0.15
Connectors | J4 | 1 | Header 1x4 | Generic 2.54mm | THT | OLED module connection | 0.05 | 0.05
Connectors | J6 | 1 | Header 1x4 | Generic 2.54mm | THT | UART debug header | 0.05 | 0.05
Passives | FB1 | 1 | 600R@100MHz | Generic 0603 | 0603 | Ferrite bead isolating the 3V3A analog rail | 0.03 | 0.03
Passives | C1;C3-C5;C7;C9;C13;C16;C25 | 9 | 10uF | Generic X5R 0805 16V | 0805 | Bulk decoupling | 0.03 | 0.27
Passives | C2;C6;C8;C10;C12;C14;C15;C26-C29 | 11 | 100nF | Generic X7R 0603 25V | 0603 | Bypass | 0.01 | 0.11
Passives | C11;C18-C24 | 8 | 1uF | Generic X7R 0603 16V | 0603 | Charge-pump and coupling caps | 0.02 | 0.16
Passives | C17 | 1 | 2.2uF | Generic X7R 0603 16V | 0603 | DAC charge-pump flying cap | 0.02 | 0.02
Passives | C30;C31 | 2 | 10nF | Generic X7R 0603 50V | 0603 | Encoder RC filter | 0.01 | 0.02
Passives | R1;R2 | 2 | 5.1k | Generic 0603 1% | 0603 | USB-C CC pulldowns | 0.01 | 0.02
Passives | R3 | 1 | 2k | Generic 0603 1% | 0603 | Charge current program 500mA | 0.01 | 0.01
Passives | R4;R23 | 2 | 1k | Generic 0603 1% | 0603 | LED series and fuel-gauge BAT filter | 0.01 | 0.02
Passives | R5;R7;R8;R11-R19;R25-R30 | 18 | 10k | Generic 0603 1% | 0603 | Pull-ups and pull-downs | 0.01 | 0.18
Passives | R6 | 1 | 1M | Generic 0603 1% | 0603 | Load-share gate pulldown | 0.01 | 0.01
Passives | R9;R10 | 2 | 4.7k | Generic 0603 1% | 0603 | I2C pull-ups | 0.01 | 0.02
Passives | R20-R22 | 3 | 100k | Generic 0603 1% | 0603 | Jack detect and battery divider | 0.01 | 0.03
Passives | R24 | 1 | 0.01R | Generic 1206 1% 1W | 1206 | Fuel-gauge sense resistor | 0.10 | 0.10
Off-board | BT1 | 1 | LiPo 402535 400mAh | Generic 402535 | 4x25x35mm | Single-cell LiPo with protection | 5.00 | 5.00
Off-board | DS1 | 1 | OLED 0.96in I2C | SSD1306 128x64 module | 27.3x27.8mm | Display module 4-pin I2C | 3.00 | 3.00
Fabrication | - | 1 | PCB | JLCPCB 4-layer 80x54mm | 1.6mm | Qty 5 minimum order incl shipping | 20.00 | 20.00
Fabrication | - | 4 | M2 heat-set insert | M2x4mm OD3.2 | brass | Front shell bosses | 0.10 | 0.40
Fabrication | - | 4 | M2x12 screw | M2x12 pan head | steel | Back-to-front fastening | 0.05 | 0.20
Fabrication | - | 1 | Filament | PETG or PLA | ~25g | Three printed parts | 1.00 | 1.00
USB | U8 | 1 | CP2102N-A02-GQFN24 | CP2102N-A02-GQFN24 | QFN-24 4x4 | USB-UART bridge with internal 3V3 regulator | 1.85 | 1.85
USB | Q2 Q3 | 2 | MMBT3904 | MMBT3904 | SOT-23 | NPN auto-reset pair driven from DTR/RTS | 0.04 | 0.08
USB | R34 | 1 | 22.1k | RC0603FR-0722K1L | 0603 | VBUS sense divider top (datasheet Fig 2.5) | 0.01 | 0.01
USB | R35 | 1 | 47.5k | RC0603FR-0747K5L | 0603 | VBUS sense divider bottom | 0.01 | 0.01
USB | R31 | 1 | 1k | RC0603FR-071KL | 0603 | CP2102N RSTb pull-up to VIO | 0.01 | 0.01
USB | R32 | 1 | 1k | RC0603FR-071KL | 0603 | Series into the bridge RXD | 0.01 | 0.01
USB | R33 | 1 | 10k | RC0603FR-0710KL | 0603 | Holds the ESP RXD idle high when the bridge is unpowered | 0.01 | 0.01
USB | R36 R37 | 2 | 10k | RC0603FR-0710KL | 0603 | Auto-reset base resistors | 0.01 | 0.02
USB | R38 | 1 | 10k | RC0603FR-0710KL | 0603 | GPIO2 strap pull-down | 0.01 | 0.01
USB | C32 C35 | 2 | 4.7uF | CL10A475KO8NNNC | 0603 | Bridge bulk bypass one per power pin | 0.03 | 0.06
USB | C33 C34 C36 | 3 | 100nF | CL10B104KB8NNNC | 0603 | Bridge HF bypass one per power pin | 0.01 | 0.03

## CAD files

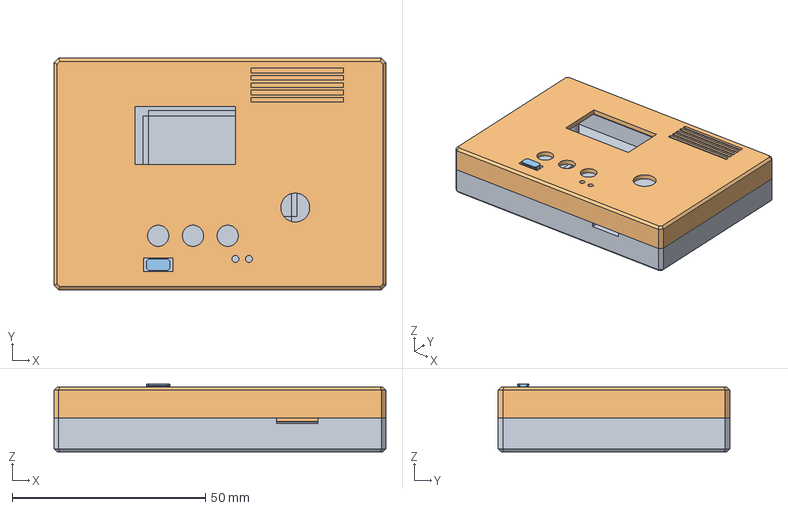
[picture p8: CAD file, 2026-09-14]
enclosure/poket-enclosure-assembly.step
86.0 x 60.0 x 17.6 mm

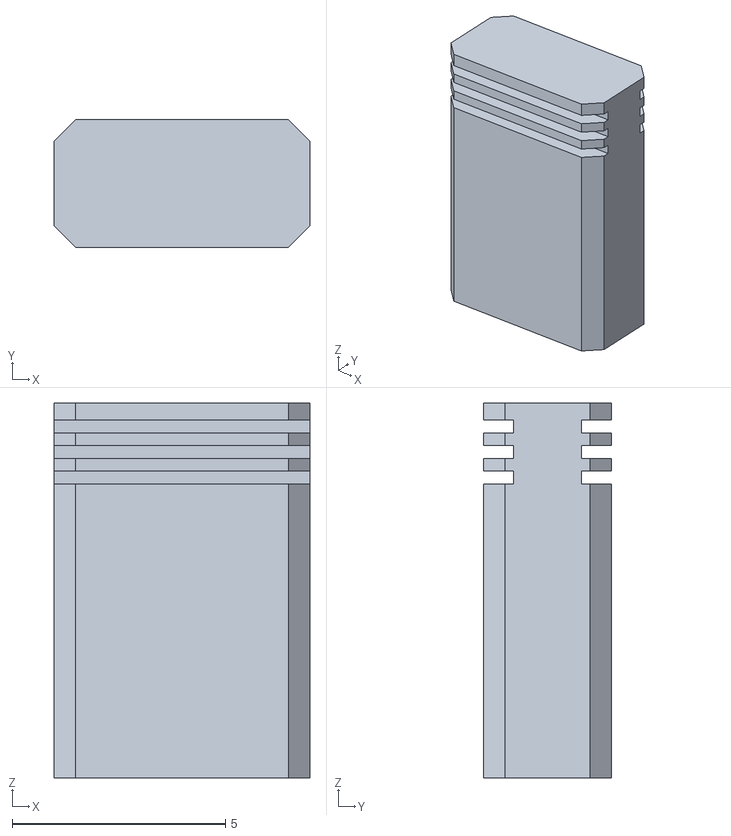
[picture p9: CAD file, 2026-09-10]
blender/slider-cap.stl
6.00 x 3.00 x 8.80

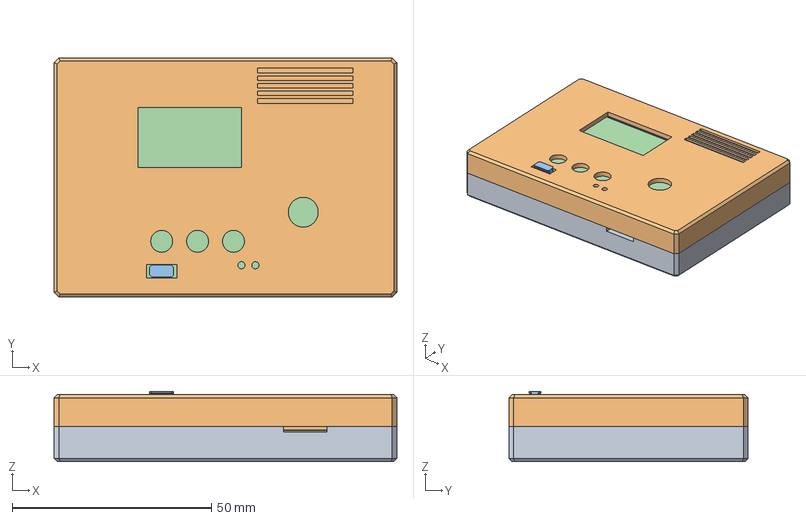
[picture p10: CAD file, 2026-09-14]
cad/poket-enclosure.FCStd
86.0 x 60.0 x 17.6 mm
BackShell
FrontShell
SliderCap
PCB_ref

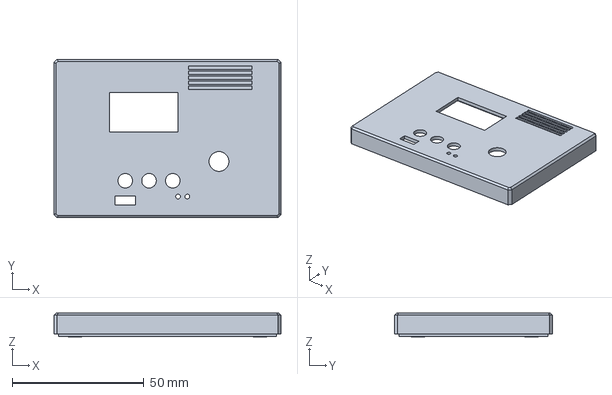
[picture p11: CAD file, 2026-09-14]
enclosure/poket-front-shell.step
86.0 x 60.0 x 9.00 mm

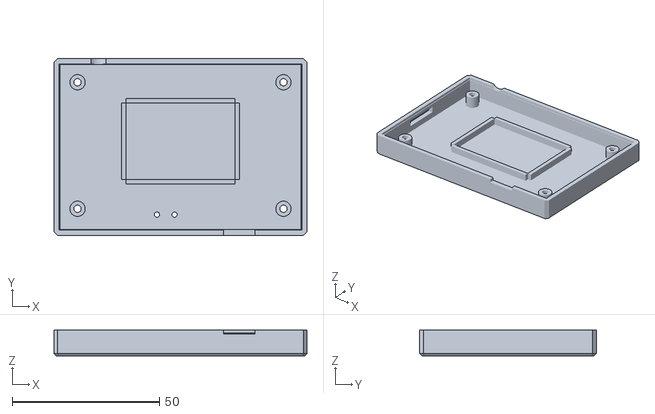
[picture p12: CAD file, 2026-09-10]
blender/back-shell.stl
86.0 x 60.0 x 8.80

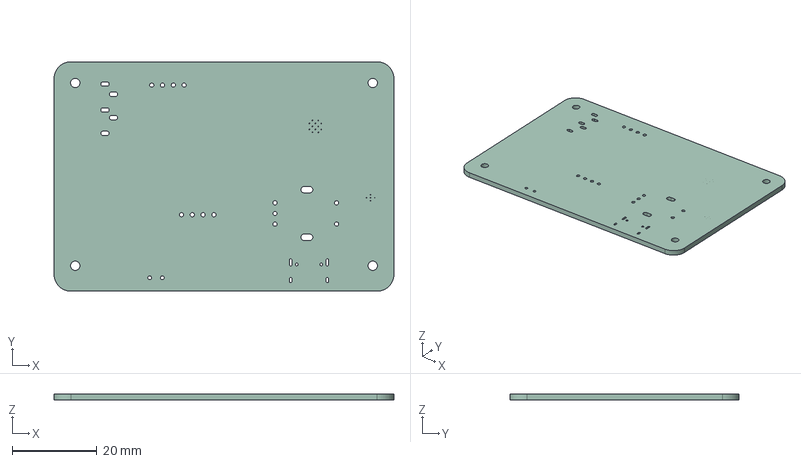
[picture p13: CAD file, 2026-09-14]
enclosure/poket-pcb.step
80.0 x 54.0 x 1.51 mm

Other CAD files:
blender/front-shell.stl
blender/pcb.stl
enclosure/poket-slider-cap.step
enclosure/poket-back-shell.step
blender/poket-ad.blend
blender/poket-hero.blend
blender/poket-remake.blend
blender/poket.blend
enclosure/poket-back-shell.stl
enclosure/poket-front-shell.stl
enclosure/poket-slider-cap.stl

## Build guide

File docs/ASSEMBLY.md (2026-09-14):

# Building a Poket

## 1. Board

Order `fab/poket-gerbers.zip` as a 4-layer 80 × 54 mm board. If you're having
JLCPCB assemble it, `fab/poket-pos.csv` is the pick-and-place file and
`docs/BOM.csv` is the parts list — you'll need to fill in the supplier part
number column first.

Hand assembly order, easiest to hardest:

1. **U5 (PAM8908)** and **U6 (BQ27441)** first, while the board is empty and you
   can get a hot plate or hot air at them cleanly. U6 is 0.4 mm pitch — use
   plenty of flux, drag solder, then wick the bridges.
2. Remaining ICs, then passives, then connectors.
3. **J2 (microSD), SW5 and SW6 go on the BOTTOM side.** Easy to miss.
4. Encoder, buttons, jack, USB-C last.

Before powering anything: check for shorts between 3V3 and GND, and between
VBAT and GND.

## 2. First power-up

1. **Battery disconnected**, slide switch off. Plug in USB-C.
2. Slide switch on. Measure 3V3 at C5 — should be 3.3 V ±3 %.
3. Check 3V3A at C7 is the same (it comes through FB1).
4. Connect USB to a computer. The CP2102N should enumerate as a USB serial port.
   If not, hold BOOT (back pinhole), tap RESET, release BOOT — that forces the
   ROM bootloader.
5. Only then connect the battery. D2 should light while charging.

## 3. Enclosure

Print all three parts from `enclosure/`:

| File | Orientation | Notes |
|---|---|---|
| `poket-front-shell.stl` | face down | no supports |
| `poket-back-shell.stl` | tray up | no supports |
| `poket-slider-cap.stl` | on its side | tiny, print with a brim |

Then:

1. Press four **M2 × 4 mm heat-set inserts** into the front shell bosses. Take
   your time — go in straight, let the iron do the work.
2. Push the slider cap onto the power switch actuator. It should be a friction
   fit; if it's loose, a dab of superglue.
3. Sit the battery in the ribbed pocket in the back shell, wire toward the
   bottom-left. Route the JST lead up the left side.
4. Drop the PCB onto the four posts, component side up.
5. Wire the OLED module to J4 (GND, 3V3, SCL, SDA — pin 1 is the square pad).
   Sit it in the front shell so the glass lines up with the window.
6. Close the shells and drive four **M2 × 12** screws in from the back.

## 4. Firmware

**Not written yet.** The board is designed around ESP-IDF with:

- `esp_a2dp_source` for Bluetooth audio out
- the SDMMC host peripheral in 4-bit mode for the card
- I2S in TX master mode to the DAC (no MCLK — the PCM5102A runs from BCK/LRCK)
- I2C for the OLED and the fuel gauge

See the pin map in `docs/DESIGN.md`.

## Gotchas that will bite you

- **The slide switch does not disconnect the battery.** It gates the LDO enable
  pin. The fuel gauge stays powered from VBAT permanently — that's deliberate,
  it needs to keep counting, but it means the cell drains slowly in storage.
- **GPIO35/36/37 are not free.** The N16R8 module uses them internally for the
  octal PSRAM.
- **There's no MCLK to the DAC.** Configure I2S accordingly or you'll get silence.
- **R24 is a 0.01 Ω sense resistor**, not a jumper. Fitting a 0 Ω here breaks
  the fuel gauge.

## Rev B additions

Populate these along with the rest of the top side:

- **U8 (CP2102N-A02-GQFN24)** — USB-UART bridge, QFN-24. Pin 1 dot faces the
  board's bottom-left. Bottom side, next to the USB-C connector.
- **Q2, Q3 (MMBT3904)** — auto-reset pair. They are *not* interchangeable with
  each other's positions: Q2 drives EN, Q3 drives IO0, and the emitters cross.
- **R34 22.1k / R35 47.5k** — the VBUS sense divider. Getting these the wrong way
  round puts 5 V on a 3.3 V pin.
- **R31 1k** — RSTb pull-up. Not 10k.

First power-up: the board should enumerate as a CP2102N USB serial port. If it
does not, check R34/R35 orientation before anything else.

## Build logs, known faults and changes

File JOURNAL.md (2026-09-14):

---
title: "Poket"
author: "hxshino"
description: "ESP32-S3 bluetooth MP3 player. microSD, PCM5102A DAC, headphone amp, LiPo, 3D printed case."
created_at: "2026-09-09"
---

# Sep 9: Scoping + part picks

Nailed down what this actually is: plays MP3s off a microSD, sends to BT
headphones (A2DP source) OR out a 3.5mm jack. OLED + encoder + 3 buttons.
LiPo with USB-C charging and a real fuel gauge.

Part hunt in the KiCad libs:
- ESP32-S3-WROOM-1-N16R8 (module, not bare chip — no RF matching to get wrong)
- PCM5102A I2S DAC. no MCLK needed, internal PLL. one less pin to burn
- PAM8908 headphone amp. charge pump = ground-centered output = no fat
  DC blocking caps in the audio path
- MCP73831 charger + DMG2301L load-share P-FET
- AP2112K-3.3 LDO
- Wanted MAX17048 for the fuel gauge but there's no symbol in KiCad and I
  wasn't confident enough in the pinout from memory. Went BQ27441-G1
  instead — symbol exists, guaranteed right. Costs me a 10mR sense
  resistor in the pack ground.

Pin map done on paper first. Had to dodge GPIO35/36/37 (octal PSRAM on
the R8 module) and 19/20 (native USB).

hero

**Total time spent: 2 hours**

# Sep 9: Schematic — power + charge block

Project created, sheet bumped to A1 because this is not fitting on A4.

Power block in. USB-C 16P with 5.1k CCs, USBLC6 for ESD. Charger at 500mA
(2k on PROG). Load share is VBUS->Schottky->VSYS, and a P-FET from VBAT
that gets turned off by VBUS on its gate.

Got the gate divider wrong the first time — 100k/100k puts the gate at
2.5V while the source sits at 4.2V, so Vgs is -1.7V and the FET is still
half on. Fixed: 10k straight from VBUS to gate, 1M pulldown. Now it's a
clean off.

Power switch is a slide switch on the LDO EN pin, not in the battery
path. No amps through a cheap slide switch.

power block schematic

**Total time spent: 2 hours**

# Sep 9: Schematic done — audio, storage, UI, ERC clean

Rest of the schematic in one sitting.

Audio chain: PCM5102A -> 1uF coupling -> PAM8908 -> 3.5mm jack. Tied SCK
low so the DAC runs off its internal PLL, FMT/DEMP/FLT low for plain I2S.
Jack has a switched tip so I get plug-detect on a GPIO for free.

microSD wired for 4-bit SDIO (not SPI) with 10k pullups on CMD and all
four data lines. Card detect on the DM3AT's detect switch.

Pin map final. Dodged IO35/36/37 (PSRAM), IO19/20 (USB), and left the
strapping pins (IO0/3/45/46) alone except boot.

ERC caught two things:
1. BQ27441 BAT pin "not driven" — it sits behind a 1k filter resistor so
   nothing drives it as far as ERC cares. PWR_FLAG on that net.
2. I'd stuck a PWR_FLAG on VBAT, which is already driven by the charger's
   VBAT output pin. Two power outputs on one net = error. Moved it.

Also caught myself wiring the encoder wrong — put GND on B and the signal
on C. On the KiCad symbol C is the common. Swapped.

0 errors, 0 warnings.

schematic

**Total time spent: 4 hours**

# Sep 10: PCB placement, and a fight with the ESP32 footprint

Board is 80 x 54 mm, 4 layers (sig / GND / GND / sig). Went 4-layer because
I wanted solid ground under the DAC and the SDIO bus, and JLC 4-layer is
barely more than 2.

Placement logic: front face is what you look at, so screen + buttons +
knob live on top. microSD went on the BOTTOM of the board so the slot
lines up with the left wall and the top side isn't eaten by a 15mm socket.
BOOT and RESET also went to the bottom — pinholes in the back shell
instead of ugly holes in the face.

Two things ate a lot of time:

**The ESP32-S3-WROOM-1 footprint has a giant antenna keepout zone baked
in** — 48 x 21mm, and it's a real copper keepout, not just a drawing. Its
courtyard outline is the same shape, so every part within 24mm of the
module "overlapped" it and DRC would have screamed. Deleted the zone from
the board instance and replaced the courtyard with a plain rectangle
around the module body, then shaped my own ground pours to leave a
52-74mm x 0-9.5mm notch open under the antenna. Same intent, sane size.

**I nuked the wrong zone the first time.** My paren-matcher found
`(zone_connect 2)` inside a pad before it found the actual `(zone ...)`
block and deleted that instead. Then on the second try I ate a keepout
belonging to the microSD footprint. Restored from backup twice. Third
attempt matched on `\n\t\t(zone\n` and checked the polygon coords before
deleting. Lesson: assert on something unique before you delete.

Also got bitten by 3.0mm pitch on 0603 rows — the courtyard is 3.05mm
wide, so a 3.0 pitch is a 0.05mm overlap. Everything is on 3.5 now.

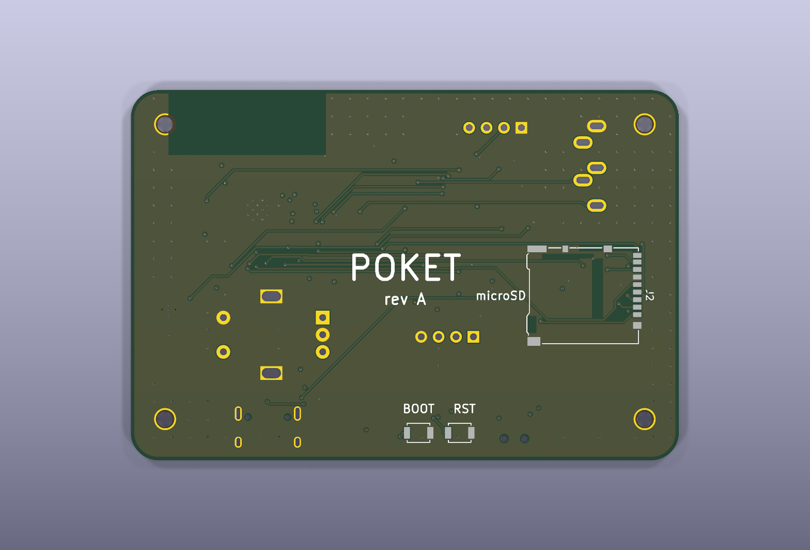
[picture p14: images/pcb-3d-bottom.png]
pcb bottom


**Total time spent: 5 hours**

# Sep 10: Enclosure

FreeCAD's RPC wasn't answering so I gave up on the GUI and scripted the
whole thing headless with FreeCADCmd. Actually nicer — the case is a
parametric script, so when the board moves the case follows.

86 x 60 x 16.8mm, two shells + a little slider cap, split just above the
PCB. Front shell has the display window, 3 button holes, the encoder shaft
hole, two LED pinholes, the power-slider slot, and a set of debossed vent
slots top-right that do nothing except make it look like it does something.
Back shell is a tray: 4 posts hold the PCB, ribs pen the battery in, M2
screws come in from the back into heat-set inserts in the front bosses.

Two geometry bugs:
- The registration lip came out as a separate floating solid. It was
  sitting in mid-air below the front wall — the wall only starts at the
  split plane, so a lip hanging below it touches nothing. Fixed by making
  the lip overlap 1mm up into the wall so there's actual volume overlap,
  not just coincident faces.
- The slider cap was 3mm too short to reach through the front face. Only
  spotted it in the render.

Wrote a tiny pure-Python STL renderer (painter's algorithm, no numpy on
this box) to get pictures out without a GUI.

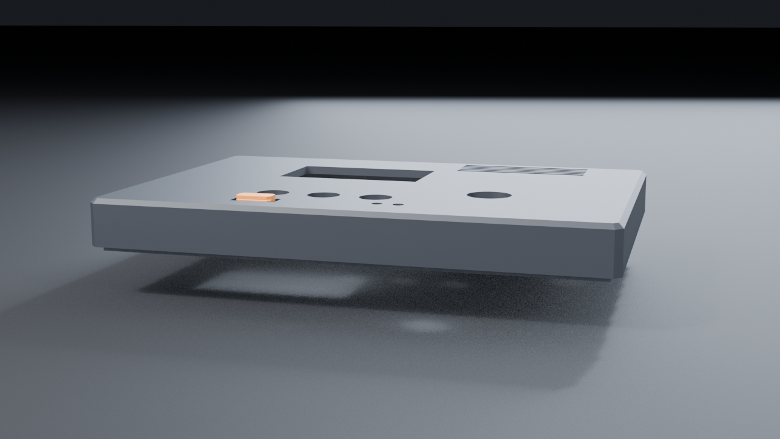
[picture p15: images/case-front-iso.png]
front

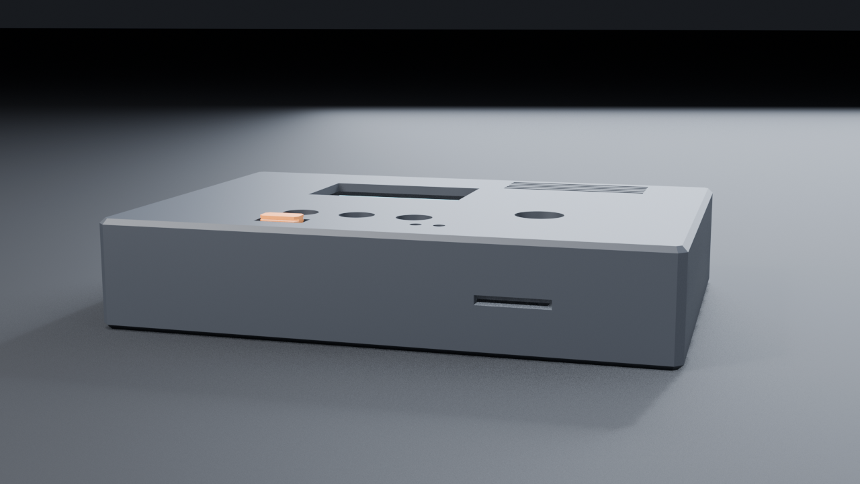
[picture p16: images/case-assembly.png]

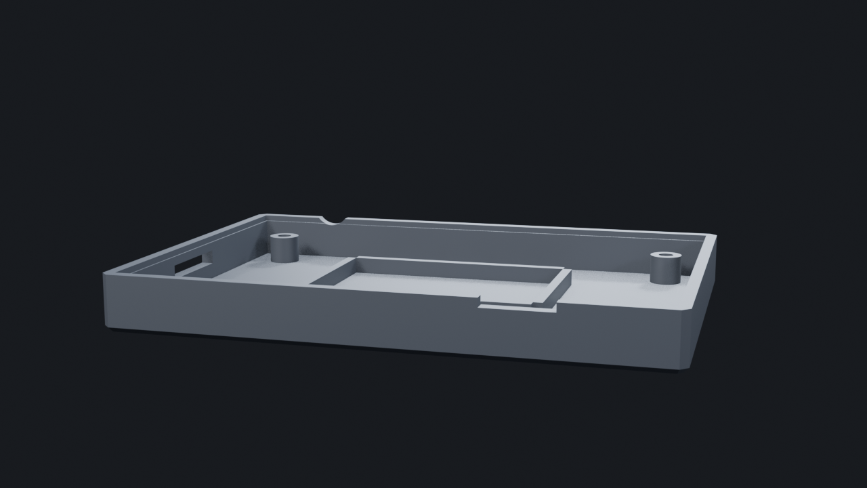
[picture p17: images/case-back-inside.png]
inside back


**Total time spent: 4 hours**

# Sep 10: Routing. Four attempts.

No autorouter installed and no way around hand-routing 150 nets, so I
pulled freerouting. It needs a display — headless mode throws
HeadlessException — so it runs on the real X display and just doesn't
show a window worth looking at.

**Pass 1.** Routed, imported, 91 unconnected. Almost all GND: my copper
pours were sitting there unfilled. Filled them from a pcbnew script
(`tools/fill_zones.py`), down to 30. Set pad connection to solid instead
of thermal reliefs, added 284 stitching vias, down to 18.

**Pass 2.** The stubborn ones were all on U6, the BQ27441 fuel gauge.
Moved it somewhere less cramped and re-routed. Better, still 22 left, and
still mostly U6.

Then I worked out why. U6 is an SON-12 with 0.4 mm pad pitch. The DSN was
telling freerouting to use 0.2 mm traces with 0.2 mm clearance — 0.4 mm
of space needed per escape, into a 0.4 mm pitch. **It was geometrically
impossible and the router had been quietly giving up on it for two
passes.** Same story on the PAM8908's QFN.

**Pass 3.** Dropped clearance to 0.15 mm (JLC does 0.127), re-routed —
auto-routing finished in ten seconds instead of four minutes. Every
component-level net connected. 0 clearance errors after I remembered to
also set the netclass clearance in the .kicad_pro, since DRC reads that
and not the number I'd set through the MCP.

**Pass 4.** Noticed the router had put 439 mm of signal on In1.Cu, which
defeats the whole point of having a ground plane there. Marked In1.Cu as
`(type power)` in the DSN and ran it again. In1.Cu is now completely
clean — solid ground directly under every trace on the component side.

Left over: a handful of pour islands with a GND pad in them and no room
for a 0.5 mm via. Wrote `tools/tie_islands.py` to find each orphan island
and brute-force a spot for a via inside it using real point-to-segment
distance instead of bounding boxes (bounding boxes on diagonal traces
block half the board). Dropped to 0.4 mm vias for the last three.

Final: 741 tracks, 229 vias, 2.4 m of copper.
**0 DRC errors, 0 unconnected, 0 schematic parity.** Six warnings left,
all library bookkeeping — the mounting hole footprint name isn't in the
stock library, and two footprints differ from their library copies
because I edited them on purpose.

pcb
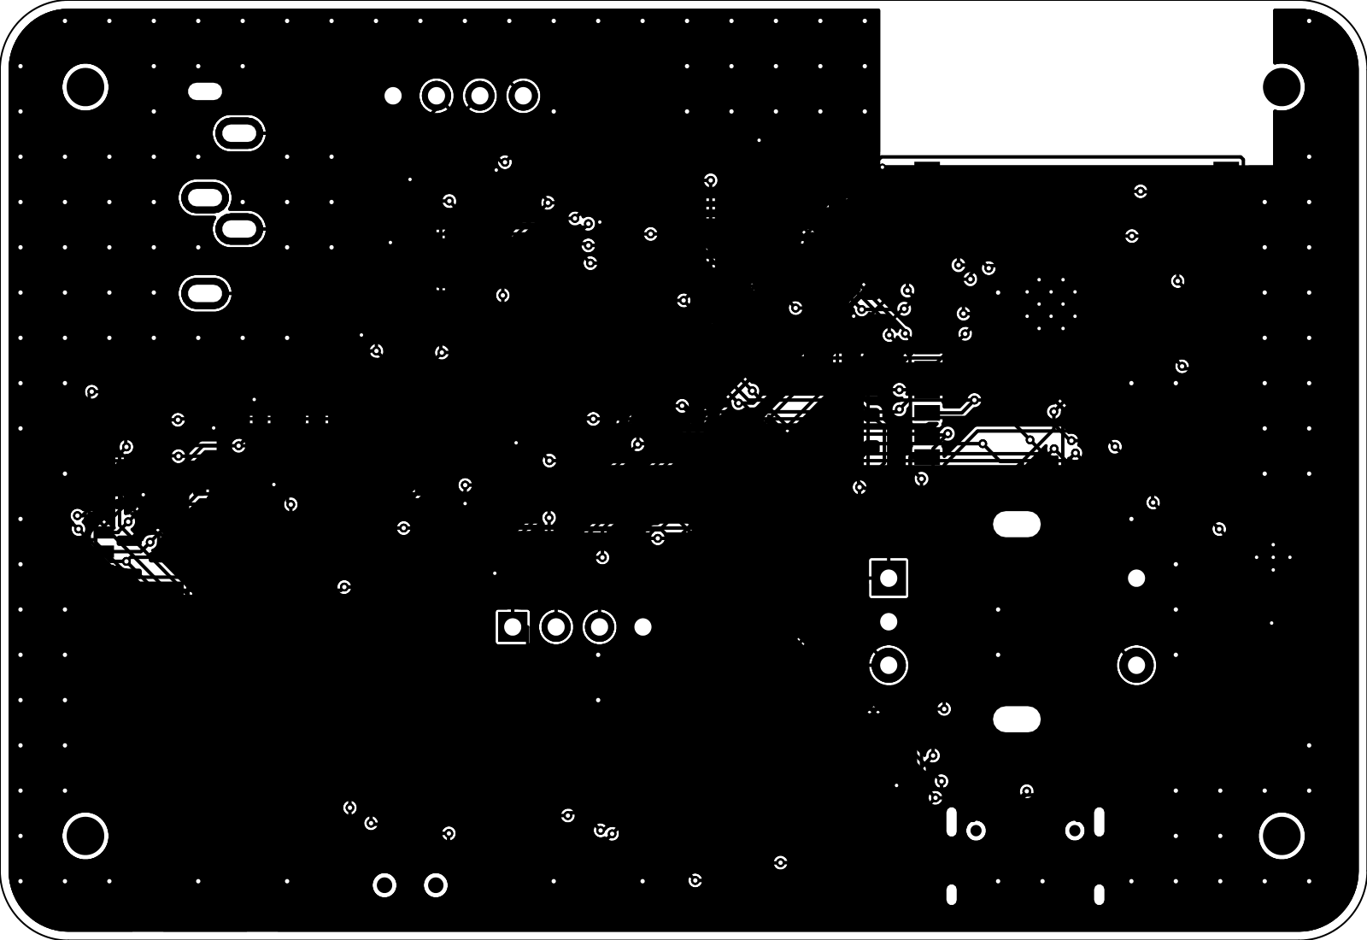
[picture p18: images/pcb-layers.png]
layers


**Total time spent: 6 hours**

# Sep 10: Fit check + wrap up

Imported the KiCad board STEP into FreeCAD, shifted it +54 in Y to convert
from KiCad's Y-down to the case coordinates, and booleaned it against both
shells. Front shell: zero interference. Back shell: 1.9 mm³, which is the
four support posts touching the underside of the board — that's what
they're for, and it lines up with the ~0.04 mm soldermask film the export
puts below z=0.

Cutouts all land where they should: USB-C and the power slider on the
bottom edge, jack on top, microSD out the left, encoder shaft and three
buttons through the face, BOOT/RST as pinholes in the back.

Shipped: gerbers + drill + pick-and-place + BOM in `fab/`, STEP and STL
for all three printed parts in `enclosure/`.

assembled

**Total time spent: 1 hour**

# Sep 10: Rebuilt the case in FreeCAD proper

The FreeCAD RPC came back up, so I threw away the headless workaround and
rebuilt the enclosure through the real GUI session. Same parametric
approach, but now I can actually look at it, and the KiCad board STEP is
loaded into the same document so the fit check is live instead of a
number in a terminal.

Immediately worth it — **the slider cap was four loose pieces.** The three
thumb grooves were cutting the full width of the part, so each one sliced
it clean through. The headless script only ever printed solid counts for
the two shells, so it slid past me and went straight into an STL I would
have printed. Grooves now bite in 0.8 mm from each long side and leave a
1.6 mm core. One solid.

Also fixed while I was in there:
- assembly STEP no longer bundles the board, and I re-exported the board
  STEP without tracks and zones — 12.5 MB down to 136 KB
- STLs meshed at 0.02 mm linear deflection instead of the default, so the
  fillets actually look like fillets (back shell 18.8k triangles)
- deleted my hand-rolled STL renderer, `cad/stlrender.py`. It existed
  purely because there was no GUI to screenshot. There is now.

Interference check with the lighter board model: **0.0000 mm³ everywhere**
— shells against each other, shells against the board, cap against the
front shell. The 1.9 mm³ I saw before was the soldermask film the old
export put below z=0.

assembled
back shell tray
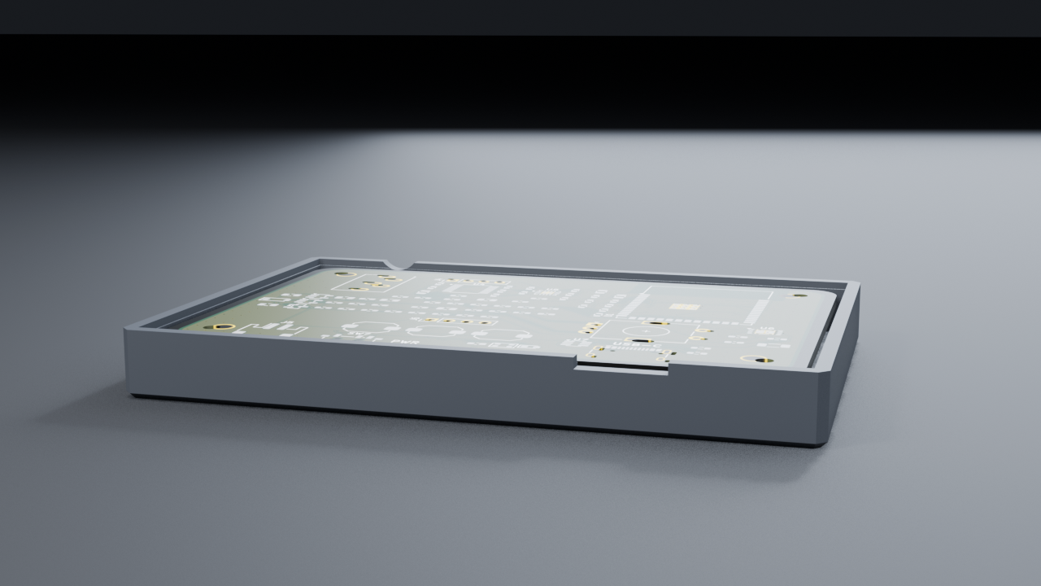
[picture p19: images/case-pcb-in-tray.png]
board in the tray


**Total time spent: 2 hours**

# Sep 10: Assembly animation in Blender

Wanted a clip that shows how the thing goes together, so: pulled the three
printed parts and the board into Blender as STLs, dropped them in from
above one at a time, then a full turntable. 194 frames, 1280x720, 30fps,
6.5 seconds.

The board is not modelled — KiCad's 3D model packages aren't installed on
this box, so the STEP export is a bare slab. Instead I rendered the board
orthographically from top and bottom with a transparent background, found
the board's silhouette in the alpha channel with numpy to get the exact
crop, and projected those two images onto the slab in object space,
picking top vs bottom by the sign of the surface normal. Traces, gold
pads and the silkscreen all read properly, and you can see the board
through the display window once the lid is on.

Three things went wrong:

- **Everything rendered pure white.** I'd copied light energies out of
  habit — 130 W area lights, 25 cm from an 8 cm object. Nine watts is
  about right at this scale.
- **Blotchy triangular shading on flat faces.** `shade_smooth_by_angle`
  needs the objects *selected*, not just active. I'd only set the active
  object, so it silently did nothing and the STL triangles showed through.
- **Blender lost the whole scene** partway through, so I rebuilt it as one
  script and saved the .blend. `blender/build_scene.py` rebuilds it from
  nothing.

Also: this Blender has no ffmpeg writer, so it renders a PNG sequence and
ffmpeg stitches it outside.

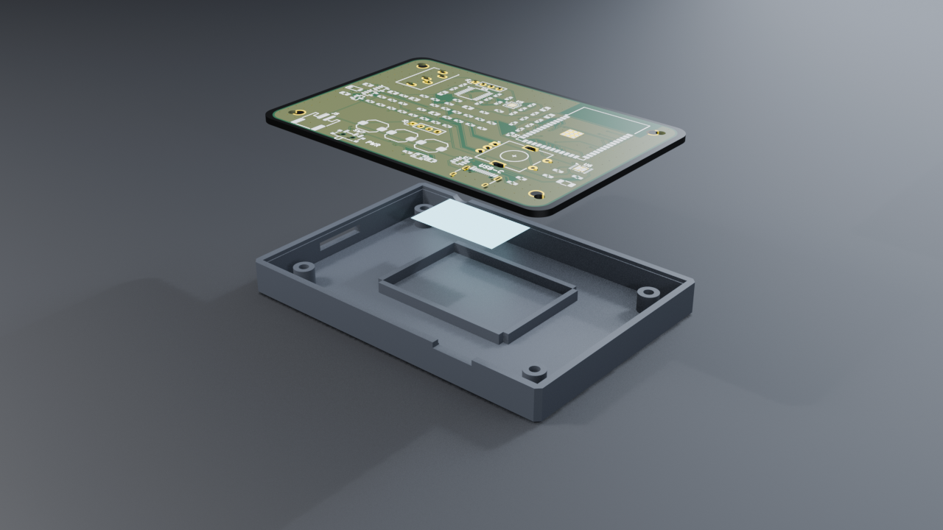
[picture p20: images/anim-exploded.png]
exploded

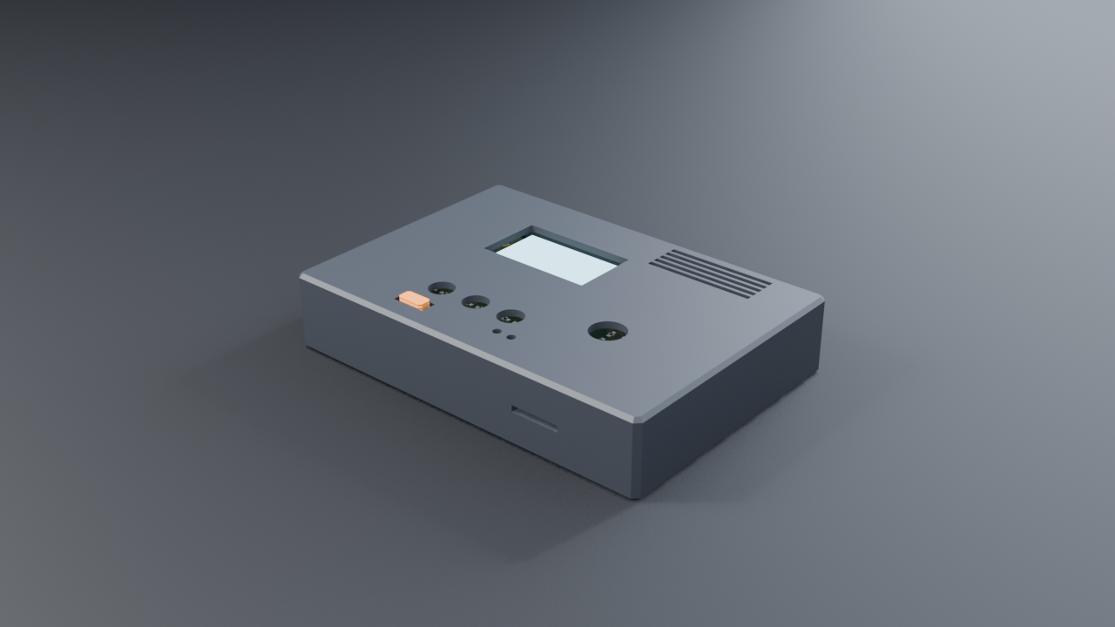
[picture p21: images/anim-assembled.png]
assembled


**Total time spent: 3 hours**

# Sep 10: Squared the edges, promo film, BOM

**Edges.** Swapped every fillet on the enclosure for a 45° chamfer — 1.2 mm on
the four outer vertical corners, 0.8 mm on the top and bottom rims. Straight
bevels, no curves anywhere you can see. Internal features (cavity, lip, rebate)
are just square now; nobody looks at them and square corners make the booleans
behave. Side effect I didn't expect: the STL dropped from 18.8k triangles to
3.8k, because there are no curved surfaces left to tessellate.

Re-ran the interference check against the board — still 0.0000 mm³ everywhere.

**Promo.** 22 seconds, five shots cut with camera-bound timeline markers: low
hero orbit, exploded build, top-down push-in, a low pass across the port side,
then a turntable. Added an emissive plane behind the display window so the
screen is lit — it goes dark when the board is out and comes back when the lid
lands, which sells the cut better than I expected.

Titles are done in ffmpeg with drawtext rather than in Blender, because this
Blender has no ffmpeg writer anyway so everything goes through a PNG sequence.

Two framing fixes: the floor plane's far edge was drawing a horizon line across
the wide shots (floor is 6× bigger now), and the low side camera was seeing the
emissive screen plane edge-on so it looked dead (raised the camera).

**Lost the .blend** partway through — deleted by accident. Cost nothing, because
`build_scene.py` rebuilds the whole scene from the STLs and the two board
renders. Folded the promo setup into the same script with a `MODE` switch so
there's exactly one file to keep.

**BOM.** 98 parts, 41 line items, ≈$46 for one unit — $24 of that electronics,
$22 PCB and hardware. Deliberately left the supplier part-number column empty:
I'm not confident enough in specific LCSC `C` numbers to write them down, and a
wrong one means the wrong part arrives. MPNs are real, prices are labelled as
estimates.

Also wrote an assembly guide and an honest submission checklist. Short version:
the design is done and manufacturable, but nothing has been built and there's no
firmware, so I'm not going to claim it works.

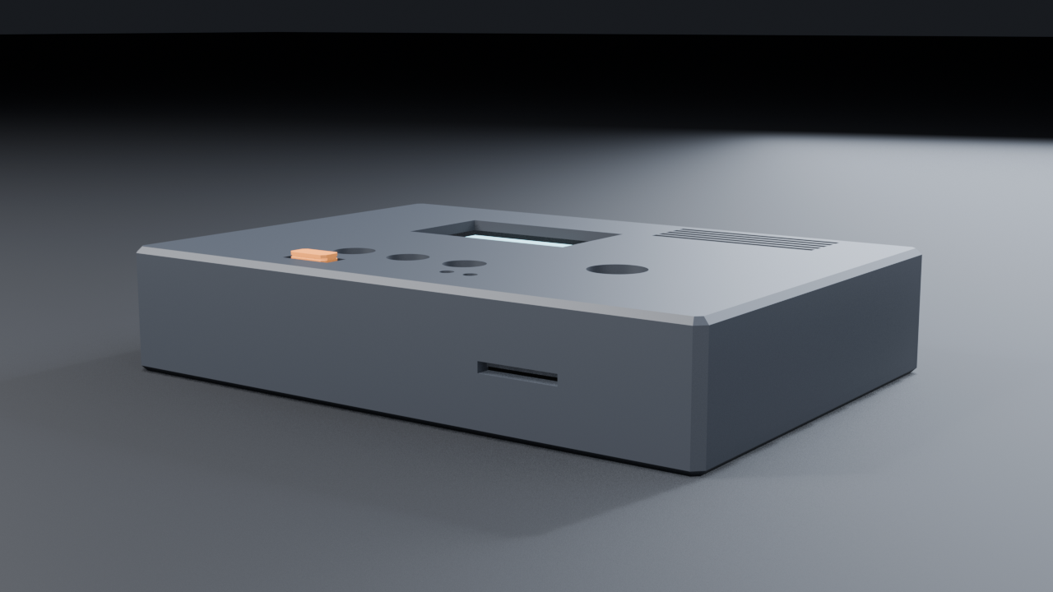
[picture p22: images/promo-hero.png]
promo

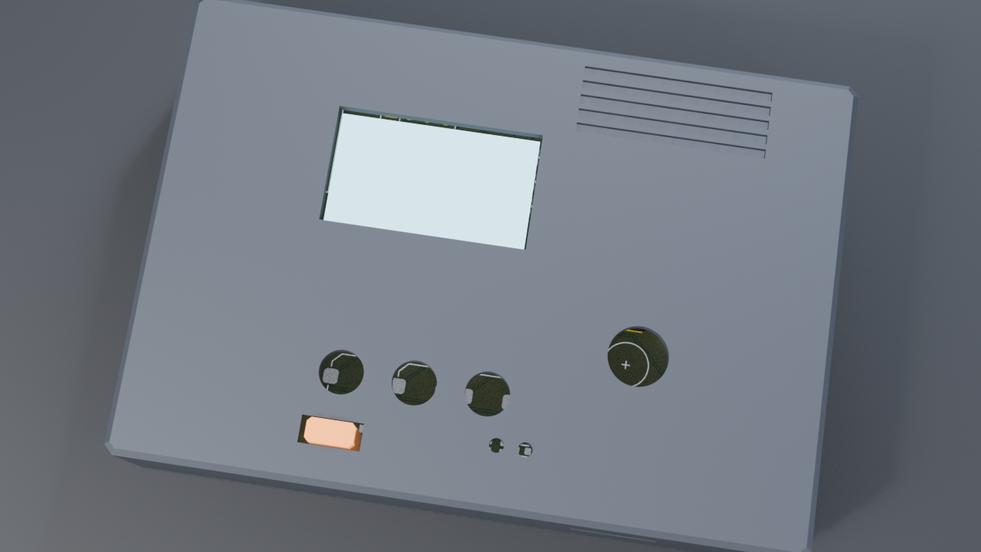
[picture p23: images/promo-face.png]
face


**Total time spent: 4 hours**

# Sep 13: Firmware — drivers, six themes, and a fight with fonts

Project got returned by a smith: no firmware in the repo, and the README was
missing pictures of the board. Fair.

Pulled the pin map straight out of the schematic netlist XML into `board.h` so
the firmware can't drift from the hardware. Then wrote down the stack:

- `drivers/` — I2C bus, SSD1306, encoder+buttons, BQ27441 fuel gauge
- `storage/` — SDMMC 4-bit mount, library scan, ID3 tags
- `audio/` — minimp3 decode into one sink interface, I2S or A2DP behind it
- `ui/` — 1-bit framebuffer + theme engine

**Themes.** Six of them. I wanted an anime theme, a minimalist one and so on —
but on a 1-bit 128×64 panel there's no colour to swap, so a theme has to differ
in layout, typeface, icons and motion or it's nothing. Minimal / Anime /
Terminal / Cassette / Brutalist / Y2K. Custom uploads land as *data*, never
code — a theme pack from a browser must not be able to execute on the device.

themes

**Fonts ate the day.** No PIL, no freetype on this machine, so the rasteriser
is SVG → rsvg-convert → ffmpeg → threshold. Three separate things wrong with it:

1. At 7–8px the threshold ate the stems. `n` came out as two dots, `:` as one.
   Fixed by not using an outline at all down there — hand-drew a 5×8 table.
2. At 9–10px it lost the top arm off `E`. It was thresholding the 1:1
   anti-aliased render, so a half-covered column never cleared the cut. Now it
   renders 4× and box-filters down, so the threshold sees real coverage.
3. **librsvg was ignoring `@font-face src:url()` entirely.** All nine "different
   typefaces" were the same fallback sans. Rendered an R in four faces and got
   four identical bitmaps. Naming the face by fontconfig family instead fixed
   it — the brutalist numerals are actually a serif now.

**Clipping bug.** The marquee scrolled its text and then blanked the overspill
with two 40px rectangles. Those rectangles were erasing whatever the theme had
drawn beside the line — which is why the anime face was missing its top half
for an hour. `gfx` has a real clip rect now and the marquee sets it.

**Web app prototypes.** Four directions for the page the device serves over its
own AP: J-Card, bench instrument, fab drawing, and a plain settings page as the
control. The OLED preview in all four is a JS port of `gfx.c` running the same
theme code against the same generated glyph bytes — and it paints at an
**integer** zoom with smoothing off, so one panel pixel is exactly N×N screen
pixels. Wrote a test that asserts that at 1/2/3/4/6/8/10× across all six themes.

Still to do: the app shell, the Wi-Fi + HTTP layer, `main.c`. Nothing has been
flashed to hardware.

**Total time spent: 6 hours**

# Sep 14: The S3 can't do Bluetooth audio. New MCU.

Went to build the firmware for real and the compiler stopped me: `esp_bt.h`
has no `esp32s3` directory, and `soc_caps.h` says why —

```
soc/esp32/include/soc/soc_caps.h:442:   #define SOC_BT_CLASSIC_SUPPORTED (1)
soc/esp32s3/include/soc/soc_caps.h:551: #define SOC_BLE_SUPPORTED        (1)   <- and nothing else
```

**A2DP needs Bluetooth Classic. The ESP32-S3 has BLE only.** The headline
feature of this thing — send audio to Bluetooth headphones — was never going to
work on the part I picked. `CONFIG_BT_CLASSIC_ENABLED` doesn't even exist as a
config symbol for that target.

So: new MCU. **ESP32-WROOM-32E-N16R2.** Checked the Espressif datasheet properly
this time instead of going on vibes:
- ESP32-D0WDR2-V3, Classic BT + BLE, 16 MB flash
- 2 MB PSRAM **inside the chip package** — so unlike a WROVER it doesn't eat
  GPIO16/17. Only GPIO16 is gone (PSRAM), plus 6–11 for flash.

Knock-on effects, all of them real work:

**No native USB.** The classic ESP32 doesn't have it. Added a CP2102N-A02-GQFN24
and the cross-coupled auto-reset pair. Read the datasheet rather than copying a
random schematic, and it paid for itself three times:
1. The VBUS *sense* pin must not see 5 V — abs max is VIO + 2.5 V. It needs a
   22.1k/47.5k divider. I'd have wired it straight to VBUS.
2. RSTb wants a **1k** pull-up to VIO, not the 10k I'd guessed.
3. 4.7 µF **and** 0.1 µF at *every* power pin, not one pair for the chip.

**The auto-reset transistors were backwards.** A blog described both emitters
going to ground; its own truth table contradicted that. Pulled Espressif's
DevKitC schematic and the table is right there: DTR=1,RTS=0 → EN low;
DTR=0,RTS=1 → IO0 low; both asserted → neither. That only works cross-coupled —
Q_EN base=DTR emitter=RTS, Q_IO0 base=RTS emitter=DTR. Which is the whole point:
opening a serial port asserts both, and the board must *not* reset.

**microSD moved from 4-bit SDIO to SPI.** On the classic ESP32 the 4-bit slot
puts DAT2 on GPIO12 — MTDI, the flash-voltage strap. A card's internal pull-up
holds it high at reset, tells the bootloader the flash is 1.8 V, and bricks the
boot. Espressif's own docs say so. SPI costs bandwidth nobody needs here: 320
kbps audio is 40 kB/s.

**Dropped the battery-sense divider.** Every ADC1 pin is taken by the encoder and
the three input-only buttons, and ADC2 stops working when Wi-Fi is on — exactly
when the transfer screen wants to draw a battery. The BQ27441 reports voltage
over I²C anyway.

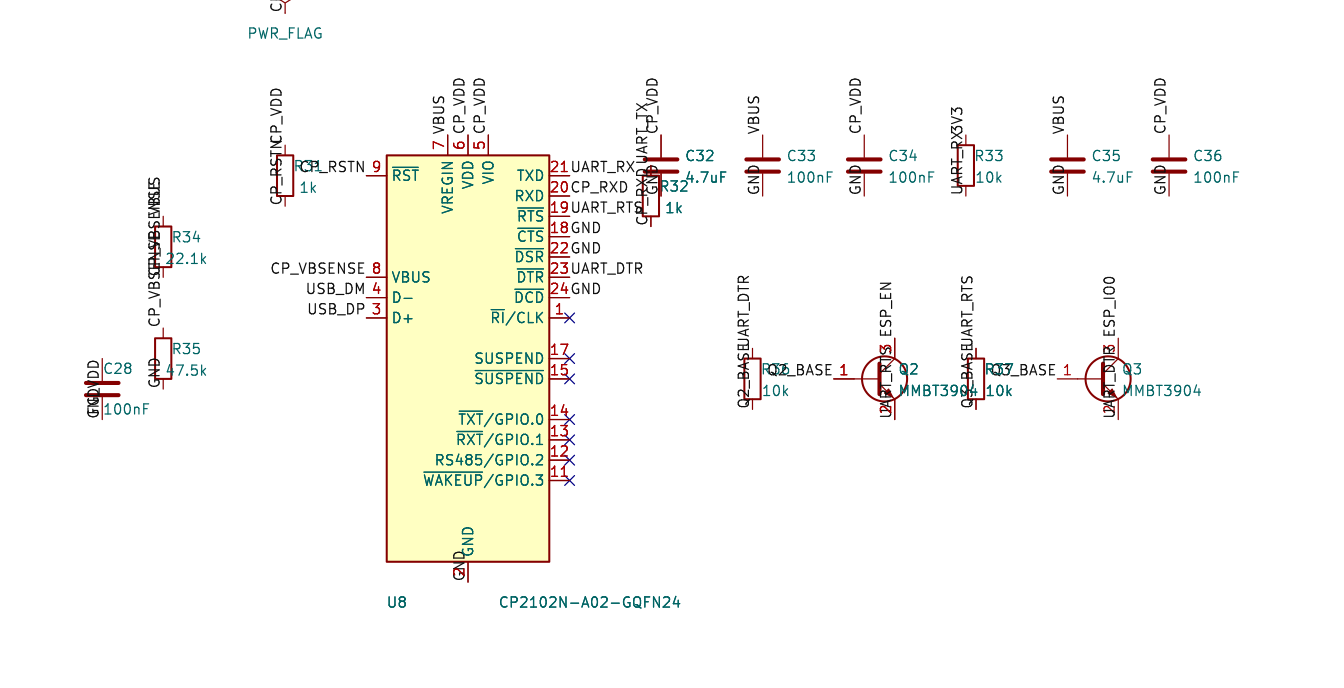
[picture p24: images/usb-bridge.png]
usb bridge


The whole block the S3 never needed: CP2102N, the 22.1k/47.5k divider guarding
its VBUS sense pin, the 1k on RSTb, a bypass pair per power pin, and Q2/Q3
cross-coupled so opening a serial port doesn't reset the board.

Schematic: ERC **0 errors, 0 warnings**. Verified all 20 firmware pins against
the netlist export — no mismatches.

PCB: ripped every track (none of it survives an MCU swap), swapped the footprint,
put the bridge block on the bottom next to the USB-C, re-routed. **DRC 0 errors,
0 schematic-parity issues, every signal net routed.** Three ground-pour fragments
are still untied — two of them hold a bypass cap's ground. Noted, not hidden.

Enclosure rebuilt against the new board: three valid single solids, and the
boolean against the real board STEP is **0.0000 mm³** on both shells. The outline
and every connector stayed put, so the case still fits.

Two hours of that was me fighting the autorouter instead of fixing placement
first. Routing is a placement problem.

**Total time spent: 7 hours**

# Sep 14: Playlists, search, and a clock that was lying

Wanted the web app to feel like a real player rather than a file dump, so:
playlists, search, shuffle/repeat, delete, and a fix for something embarrassing.

**The clock was wrong.** The position counter advanced one second every 25
animation frames. That assumes a 25 Hz display. On a 60 Hz screen it ran
**2.4× too fast** — a 4-minute track finished in 100 seconds. Position is time;
it has to be measured against a clock, not against frames. It now keeps
"elapsed E as of wall-time T" and interpolates.

Pulled the arithmetic out into `lib/clock.js` so I could test it without a
browser, which turned out to matter: my first attempt to verify it in headless
Chrome measured 0.800× and I nearly "fixed" a clock that was already correct.
Headless virtual time throttles rAF, so the *repaint* lags — I was measuring the
repaint cadence, not the clock. With a fake time source in node it's exact:
10 s of wall time, 10 s of clock, pause holds, resume continues, and it never
runs past the end of the track.

**Playlists are .m3u files** in `/Music/Playlists`. Not a private binary format:
pull the card out, put it in a laptop, and every other player can read them.
Create, add, remove, reorder, delete, play.

Hit a wall building it — the link failed with *"region `dram0_0_seg` overflowed
by 16016 bytes"*. My `playlist_remove_at` held the whole playlist in a static
`char[256][192]` to rewrite it: **48 kB of DRAM**, on a chip with 520 kB total.
Rewrote it to stream line-by-line into a temp file and rename. No buffer at all,
and an interrupted write can't leave a half-truncated playlist.

Gave the player a real queue so a playlist is a first-class thing rather than
"the library, filtered". Also made **Prev** restart the track if you're more than
3 seconds in, like every other player does.

Then the unglamorous half: everything downstream of the board was still the
**old S3 design** — gerbers from Sep 10, schematic image from Sep 9, docs naming
a part that isn't on the board any more. Regenerated the lot.

board

**Total time spent: 3 hours**

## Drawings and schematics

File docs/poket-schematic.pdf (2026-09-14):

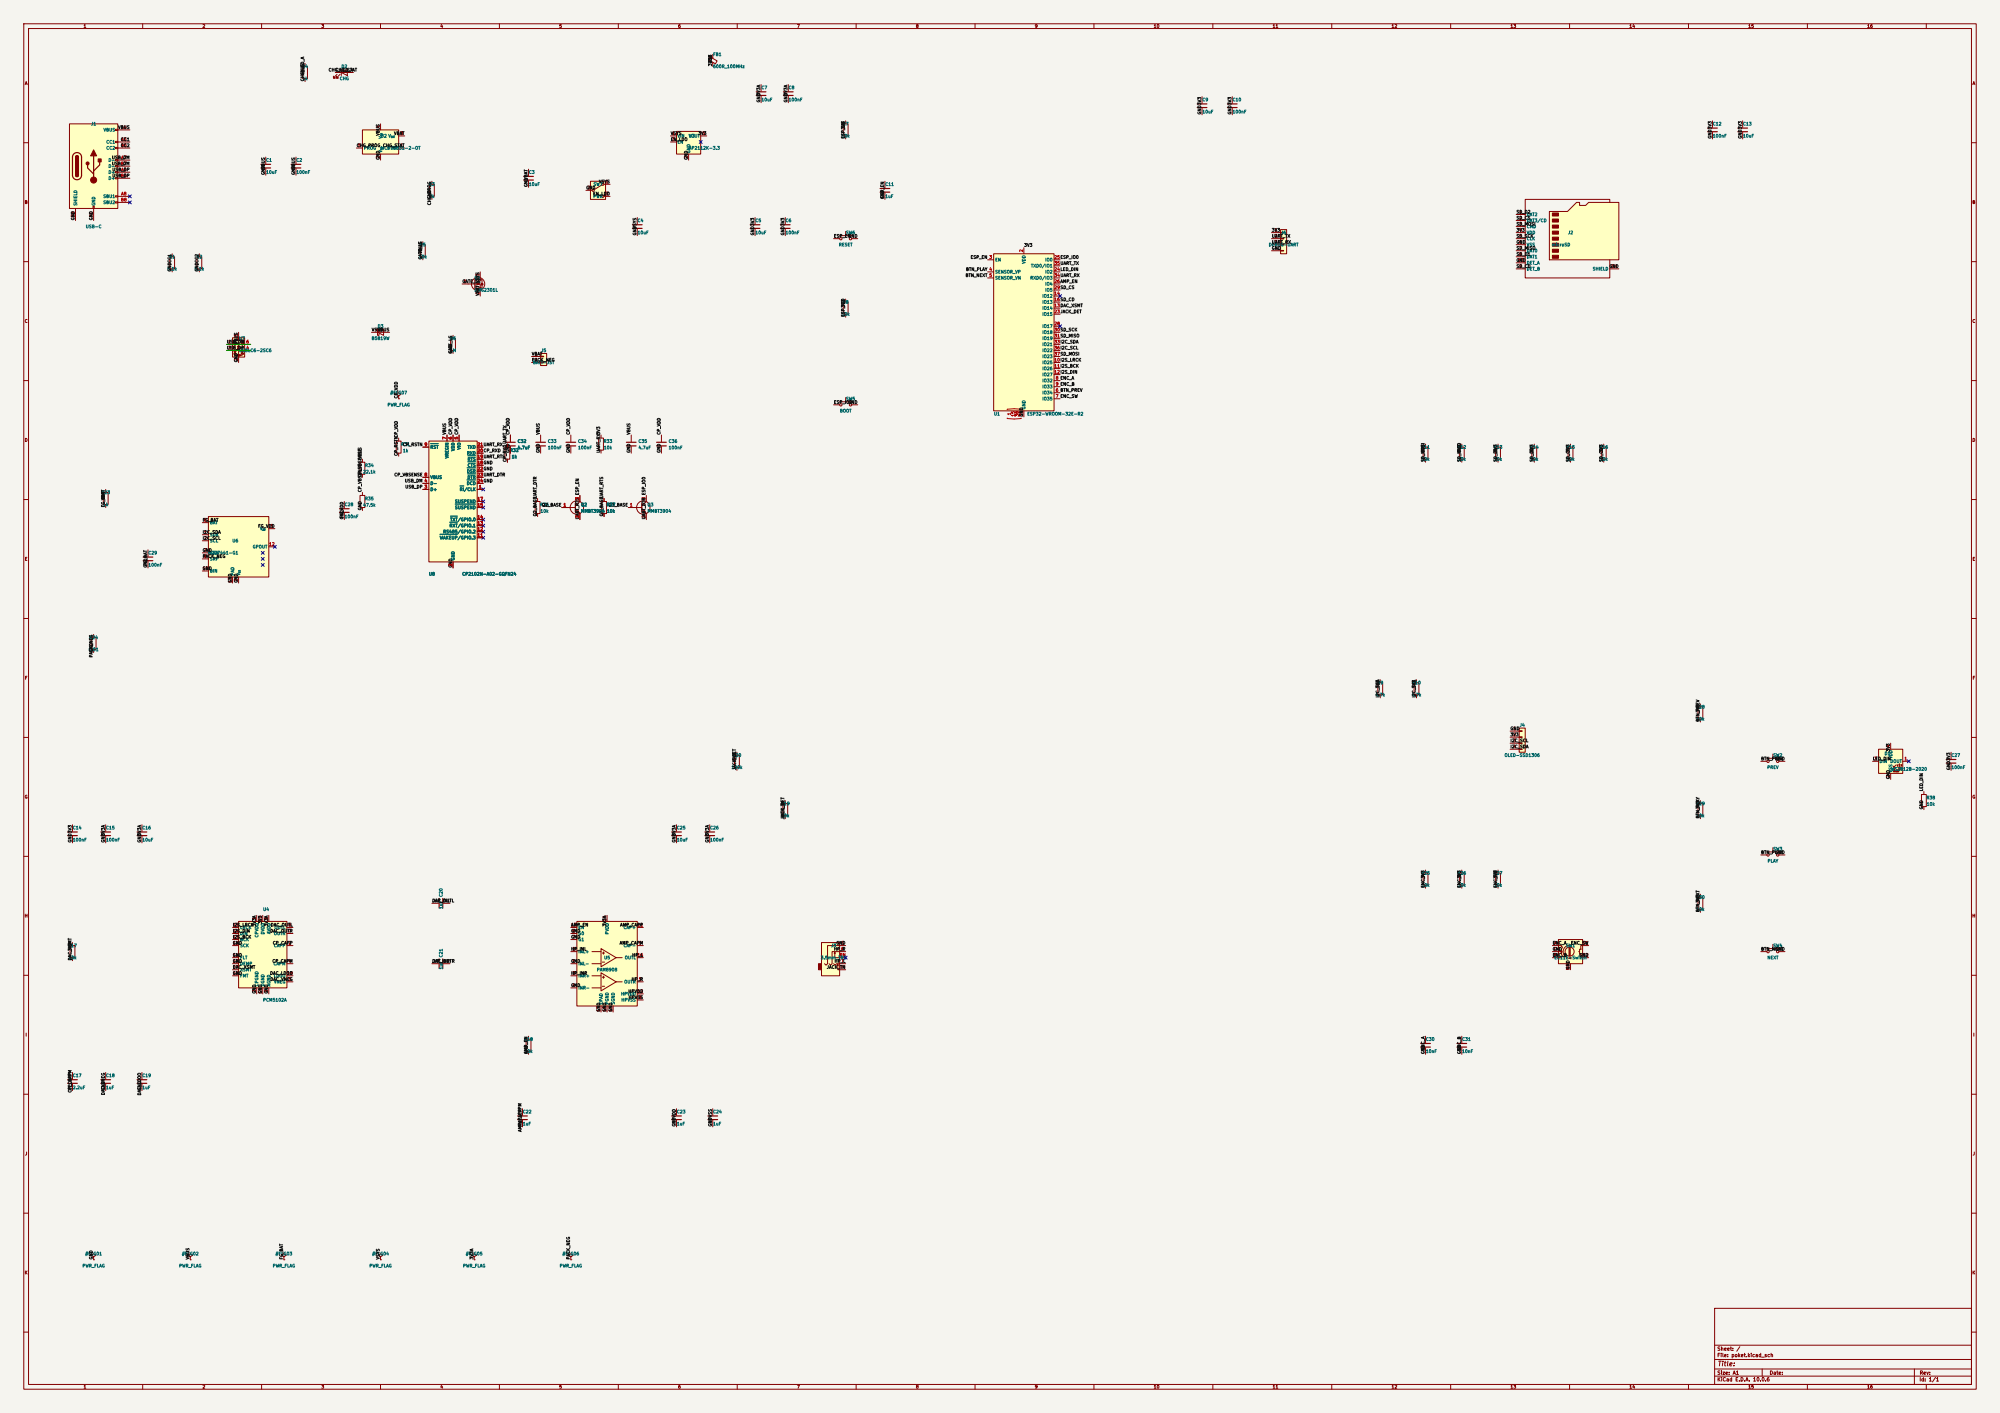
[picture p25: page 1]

Size: A1 | Rev:
KiCad E.D.A. 10.0.6 | Id: 1/1

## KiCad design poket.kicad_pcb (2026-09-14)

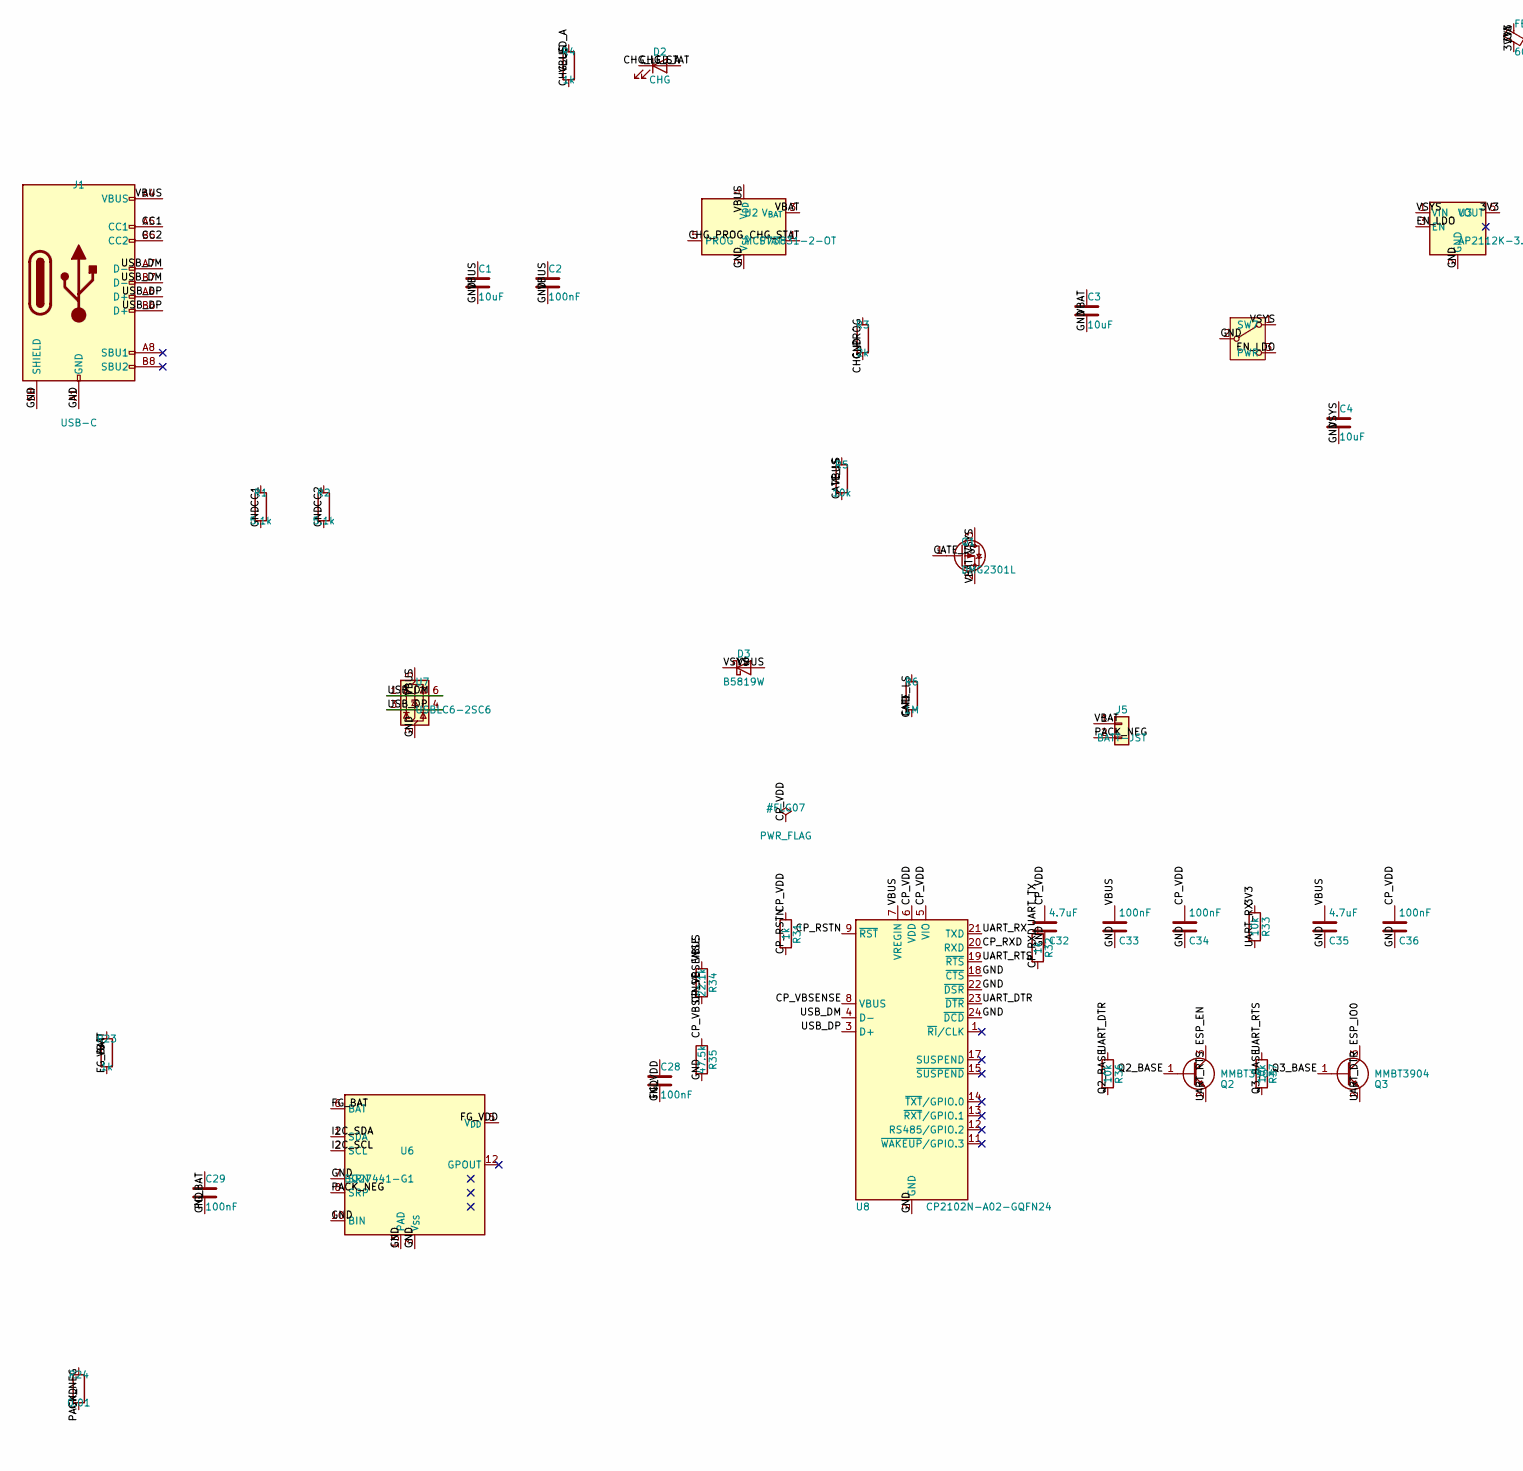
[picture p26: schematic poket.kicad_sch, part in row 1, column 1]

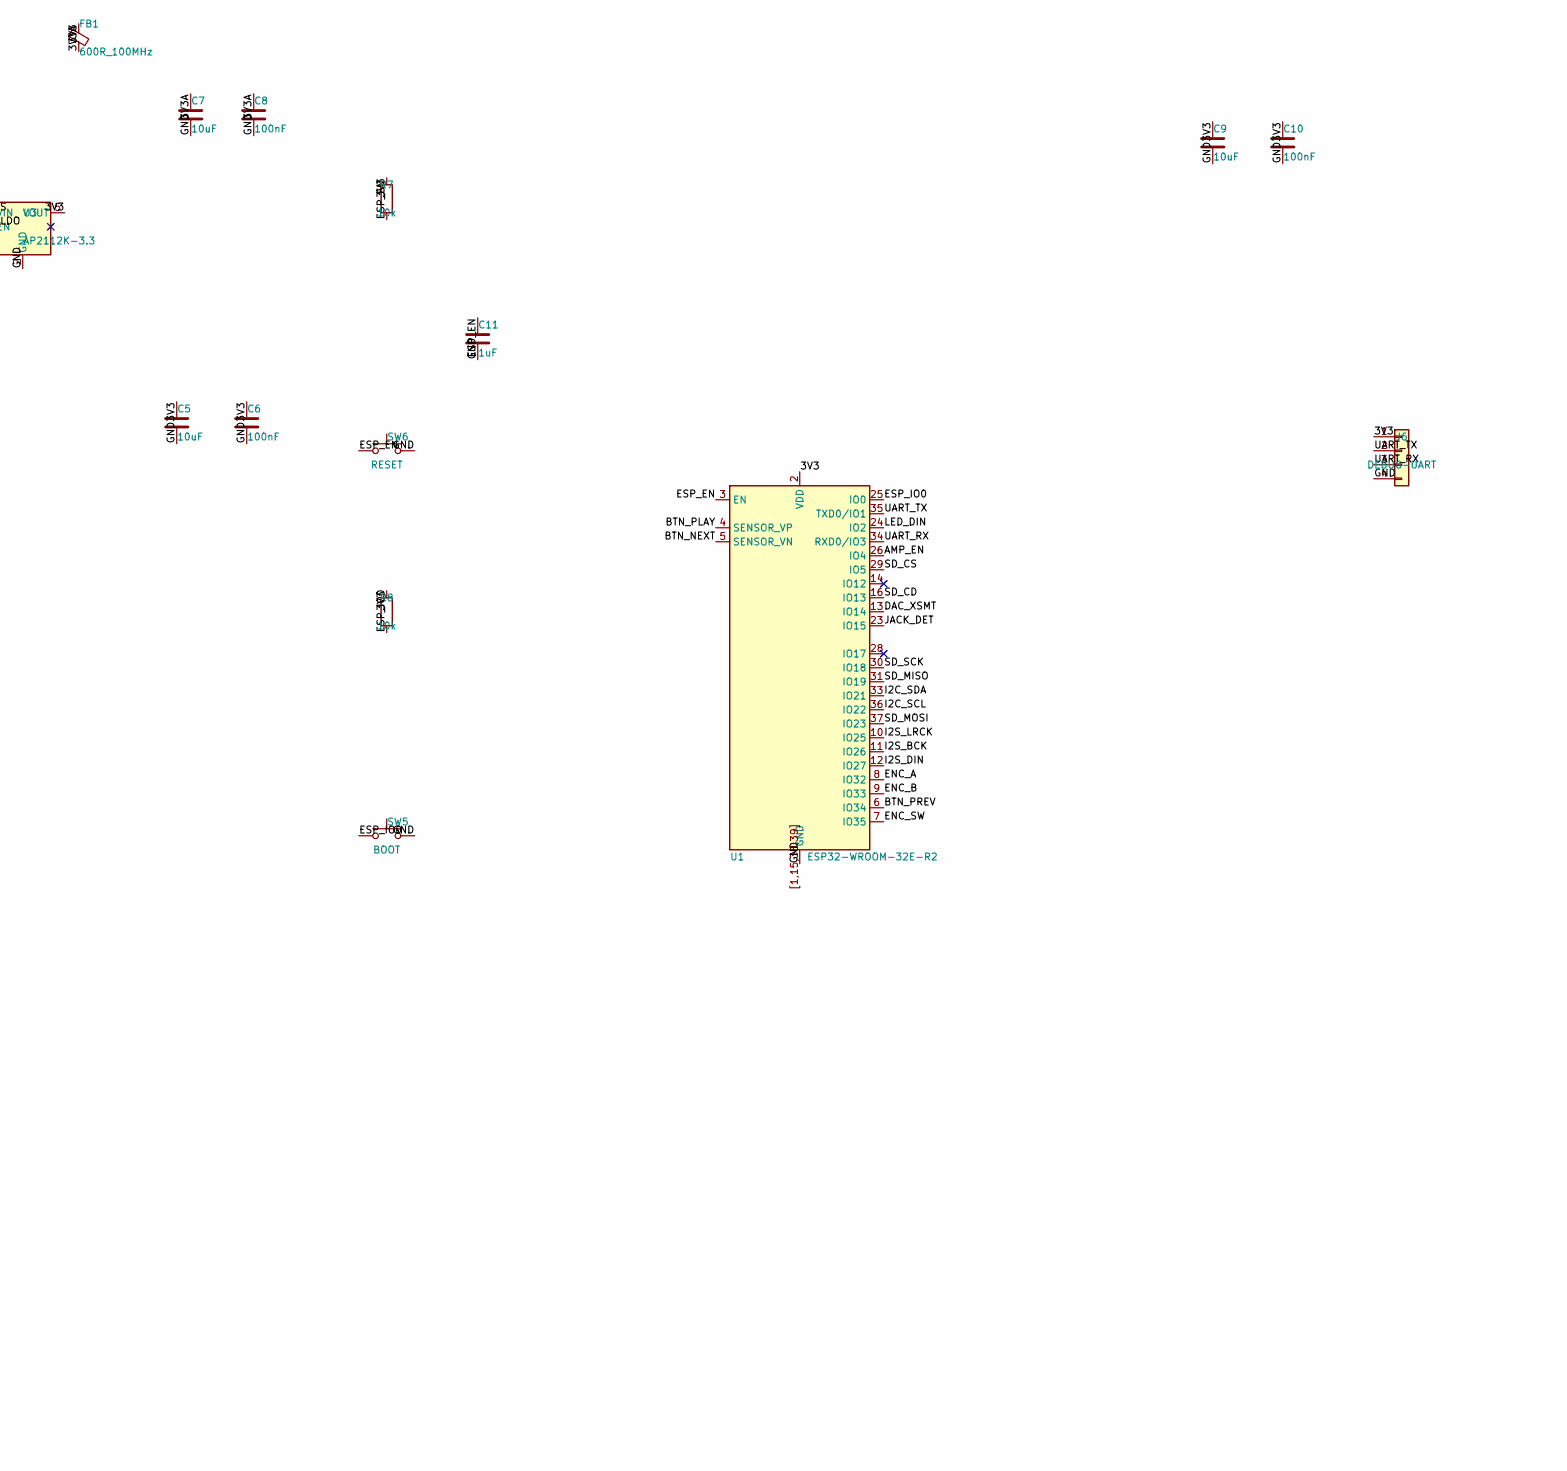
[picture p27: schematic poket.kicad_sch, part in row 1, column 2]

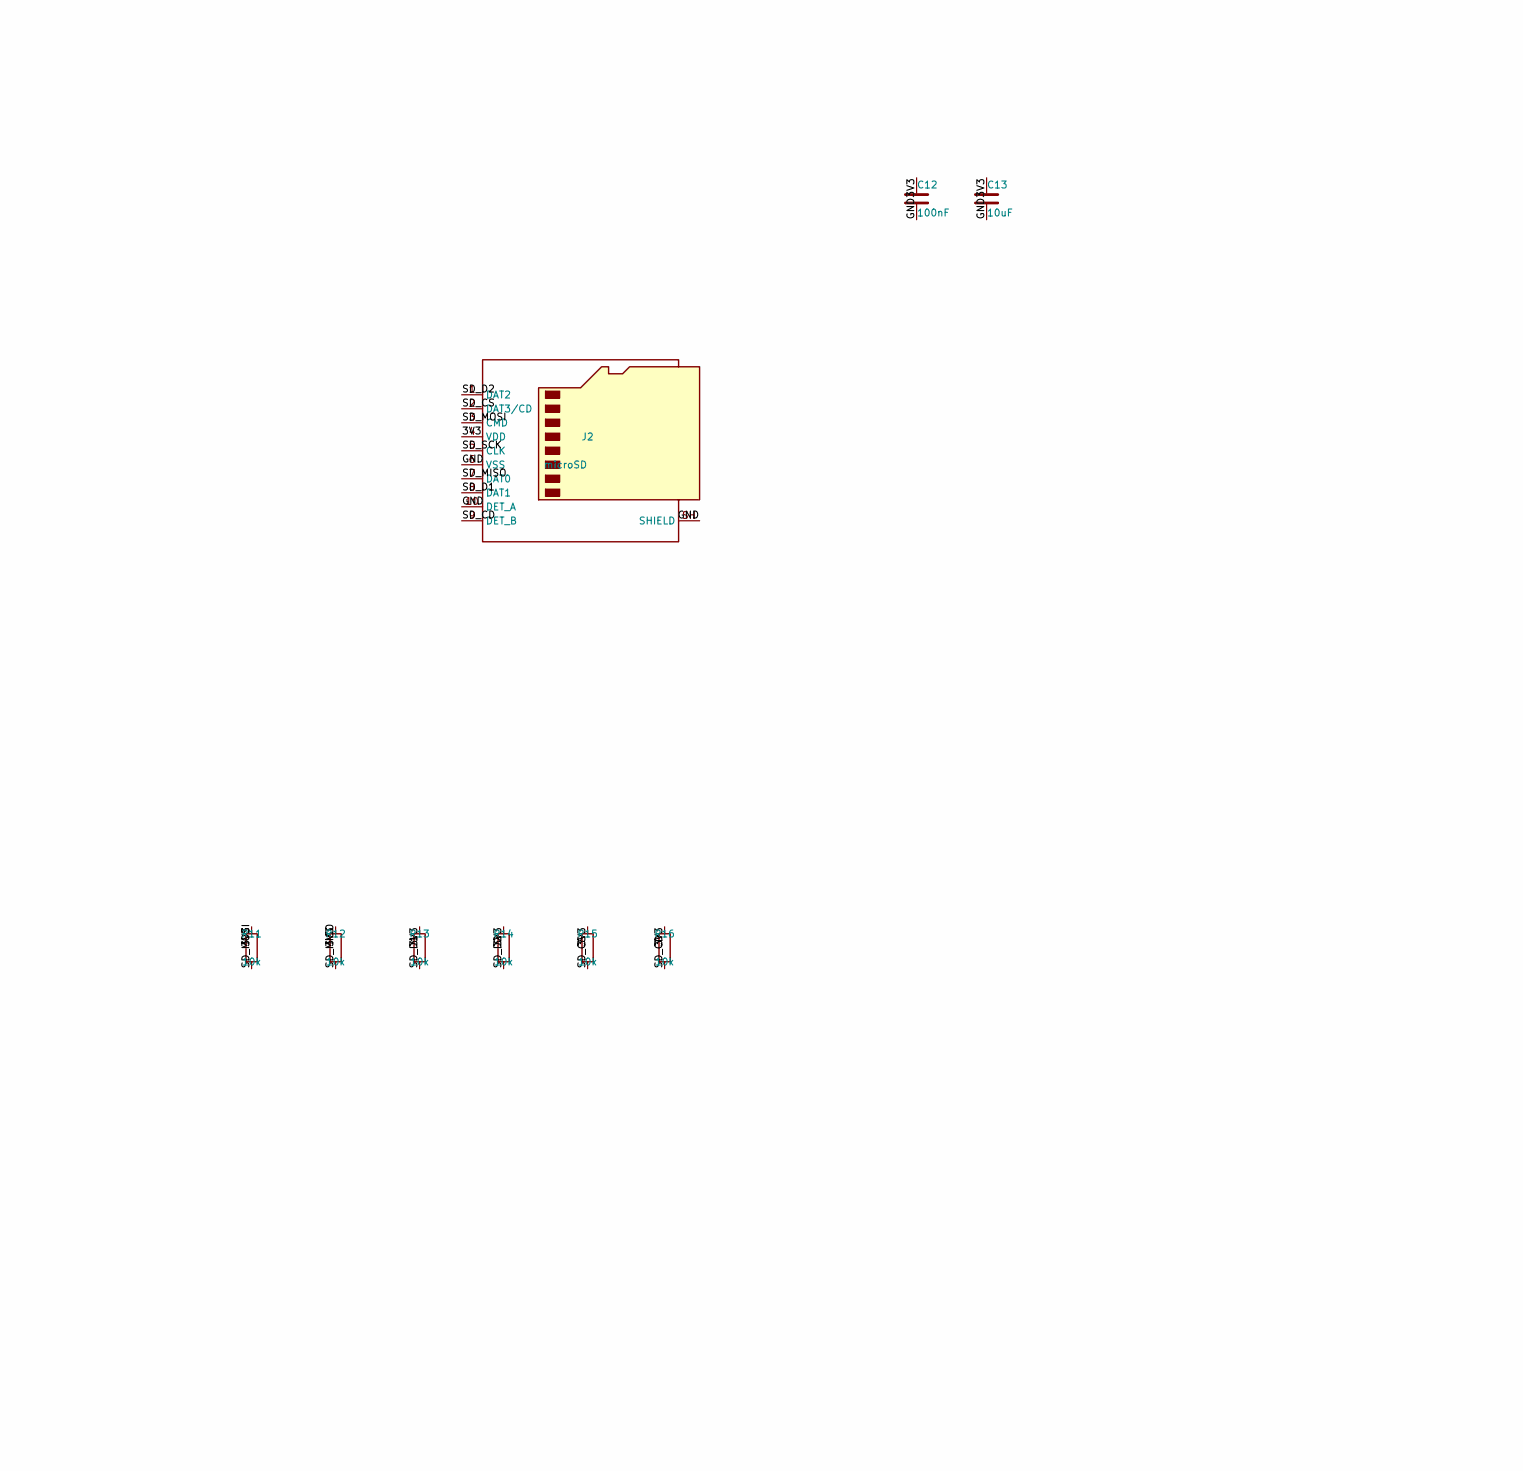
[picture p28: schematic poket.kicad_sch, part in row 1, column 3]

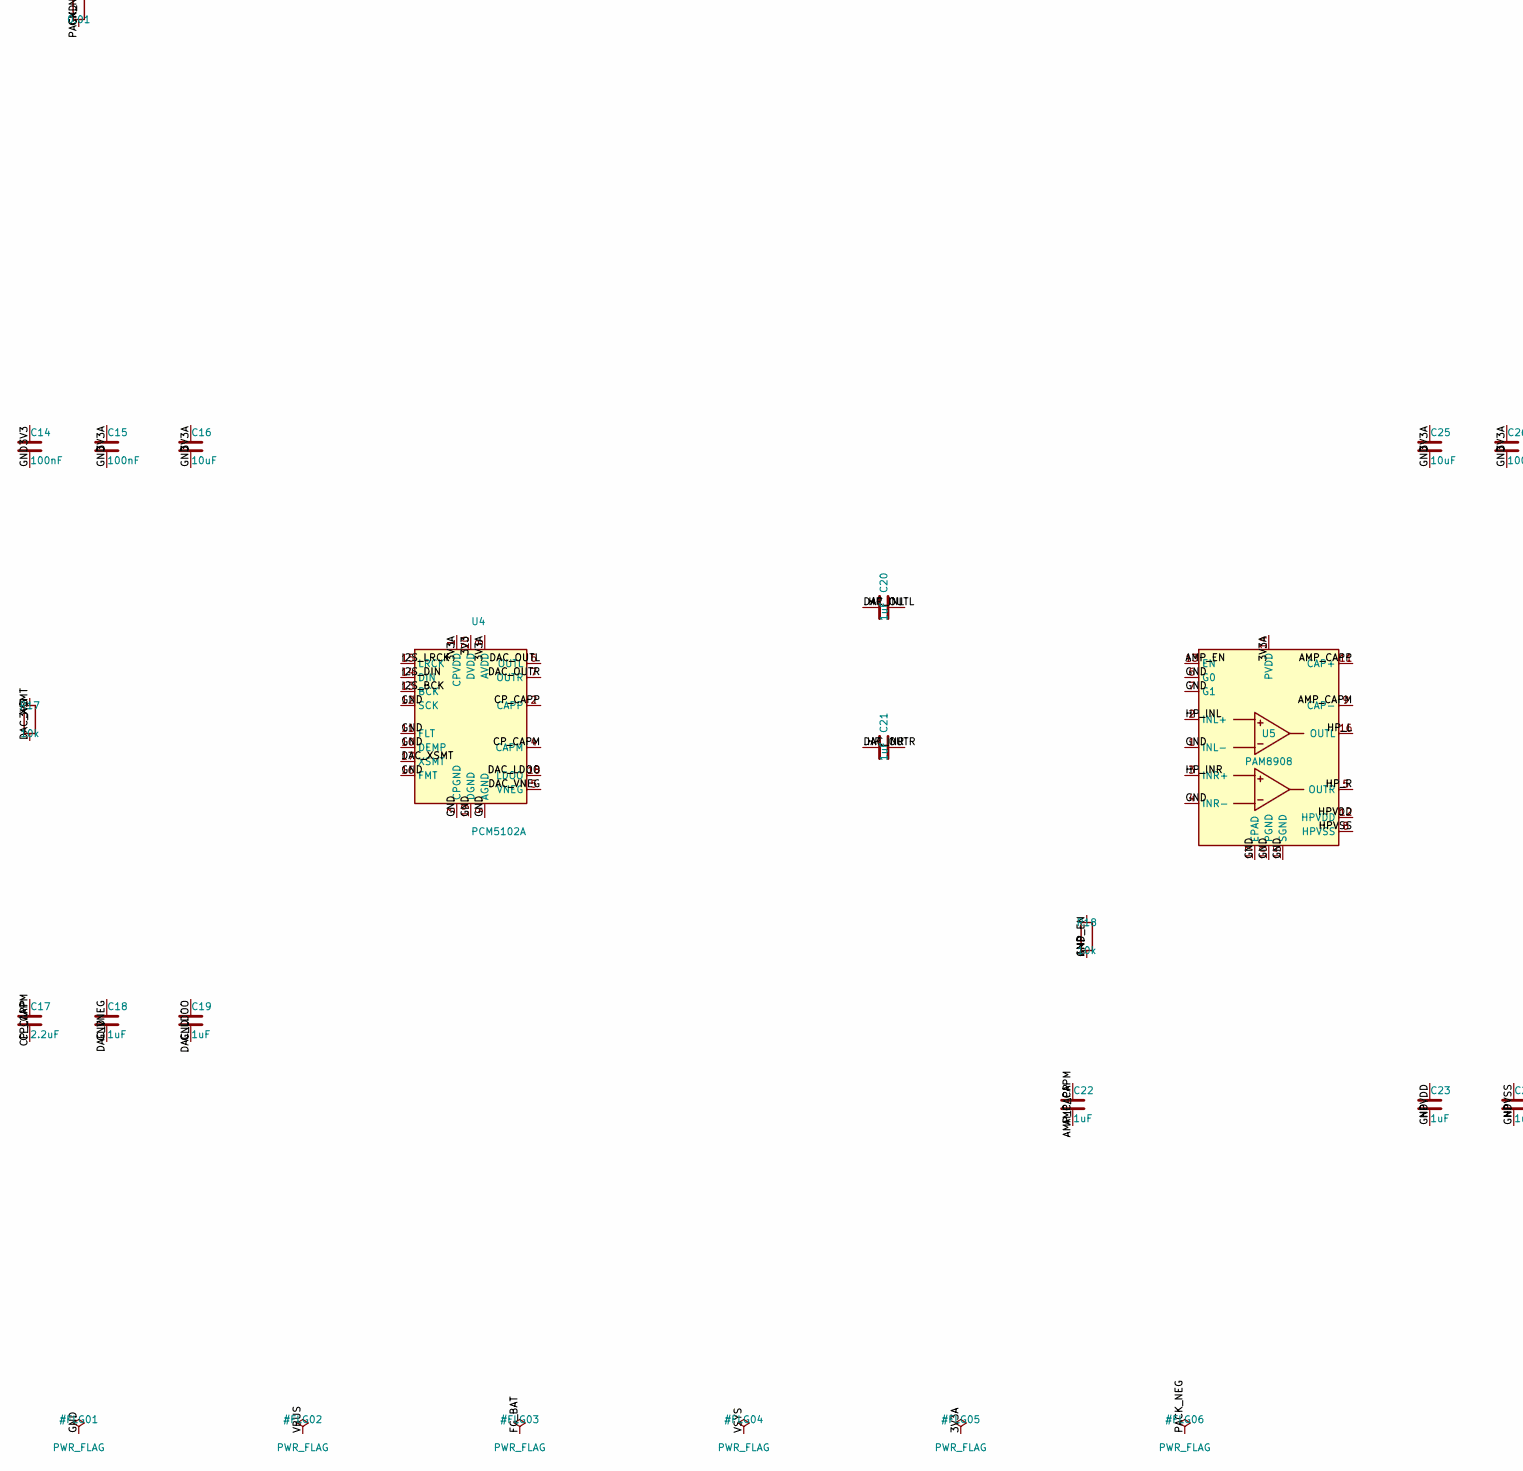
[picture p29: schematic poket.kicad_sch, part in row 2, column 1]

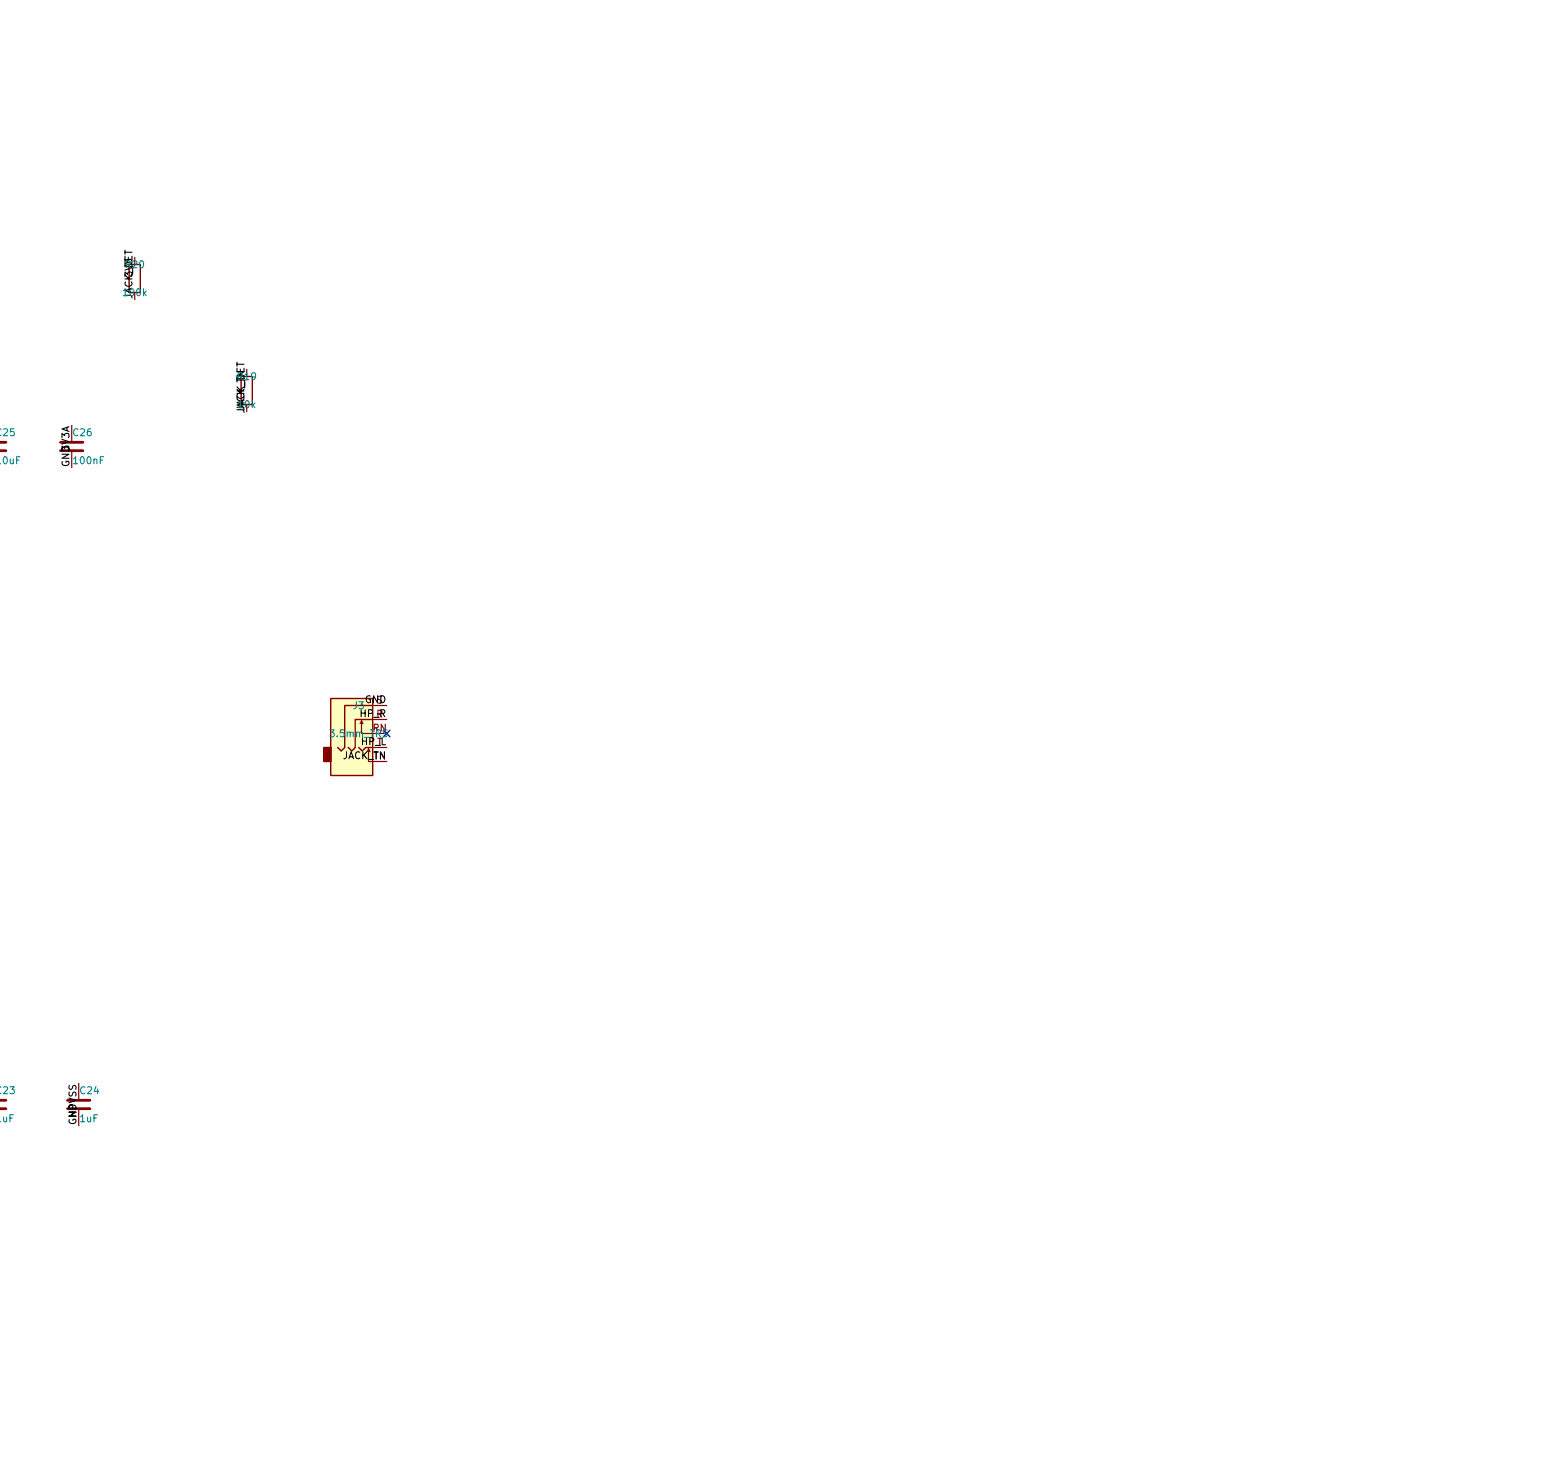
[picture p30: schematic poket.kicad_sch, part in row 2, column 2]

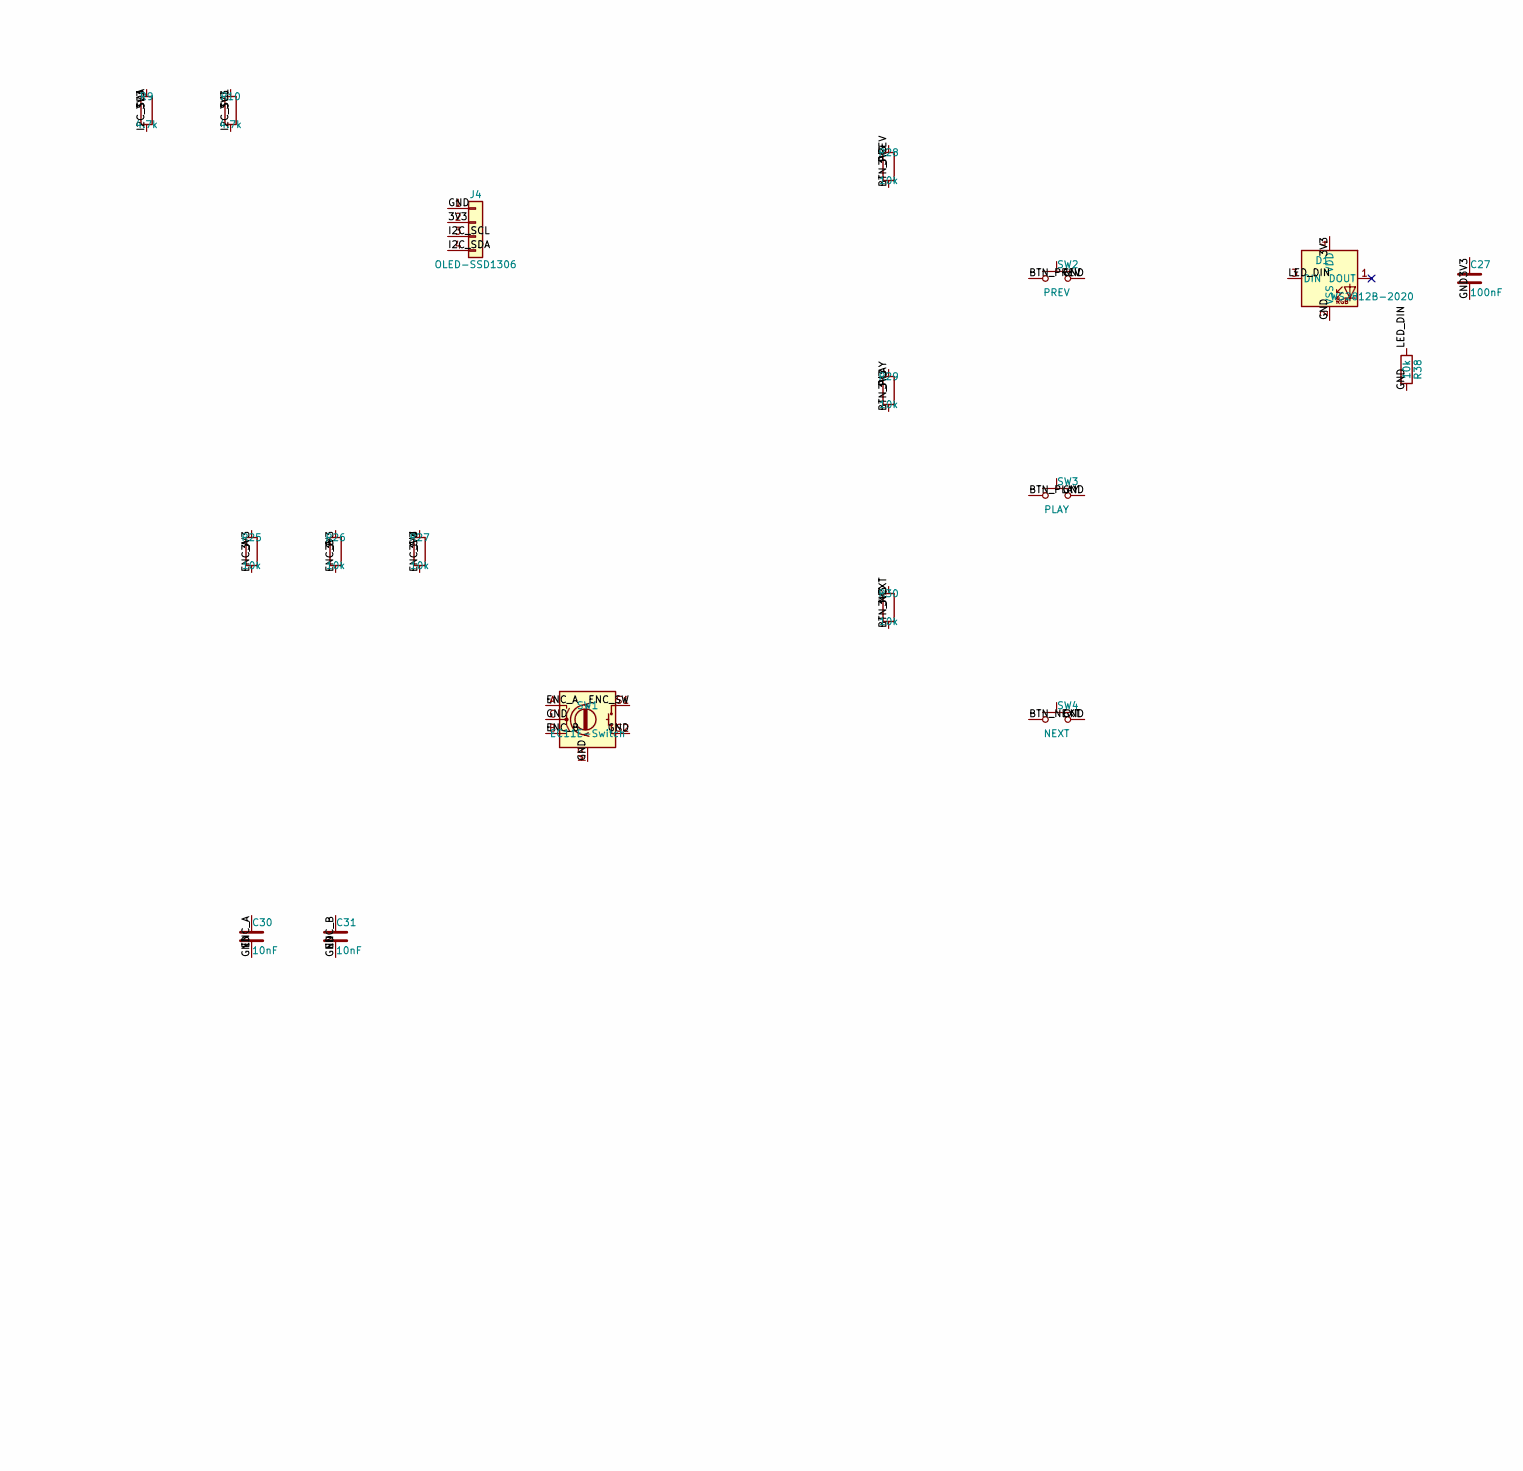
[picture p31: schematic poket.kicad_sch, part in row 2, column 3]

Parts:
C1, C3, C4, C5, C7, C9, C13, C16, C25: 10uF; C_0805_2012Metric
C2, C6, C8, C10, C12, C14, C15, C26, C27, C28, C29, C33, C34, C36: 100nF; C_0603_1608Metric
C11, C18, C19, C20, C21, C22, C23, C24: 1uF; C_0603_1608Metric
C17: 2.2uF; C_0603_1608Metric
C30, C31: 10nF; C_0603_1608Metric
C32, C35: 4.7uF; C_0603_1608Metric
D1: WS2812B-2020; LED_WS2812B-2020_PLCC4_2.0x2.0mm
D2: CHG; LED_0603_1608Metric
D3: B5819W; D_SOD-123
FB1: 600R_100MHz; L_0603_1608Metric
J1: USB-C; USB_C_Receptacle_HCTL_HC-TYPE-C-16P-01A
J2: microSD; microSD_HC_Hirose_DM3AT-SF-PEJM5
J3: 3.5mm_TRS; Jack_3.5mm_CUI_SJ1-3535NG_Horizontal
J4: OLED-SSD1306; PinHeader_1x04_P2.54mm_Vertical
J5: BATT-JST; JST_PH_S2B-PH-SM4-TB_1x02-1MP_P2.00mm_Horizontal
J6: DEBUG-UART; PinHeader_1x04_P2.54mm_Vertical
Q1: DMG2301L; SOT-23
Q2, Q3: MMBT3904; SOT-23
R1, R2: 5.1k; R_0603_1608Metric
R3: 2k; R_0603_1608Metric
R4, R23, R31, R32: 1k; R_0603_1608Metric
R5, R7, R8, R11, R12, R13, R14, R15, R16, R17, R18, R19, R25, R26, R27, R28, R29, R30, R33, R36, R37, R38: 10k; R_0603_1608Metric
R6: 1M; R_0603_1608Metric
R9, R10: 4.7k; R_0603_1608Metric
R20: 100k; R_0603_1608Metric
R24: 0.01; R_1206_3216Metric
R34: 22.1k; R_0603_1608Metric
R35: 47.5k; R_0603_1608Metric
SW1: EC11E-Switch; RotaryEncoder_Alps_EC11E-Switch_Vertical_H20mm
SW2: PREV; SW_Push_1TS009xxxx-xxxx-xxxx_6x6x5mm
SW3: PLAY; SW_Push_1TS009xxxx-xxxx-xxxx_6x6x5mm
SW4: NEXT; SW_Push_1TS009xxxx-xxxx-xxxx_6x6x5mm
SW5: BOOT; SW_SPST_B3U-1000P
SW6: RESET; SW_SPST_B3U-1000P
SW7: PWR; SW_SPDT_PCM12
U1: ESP32-WROOM-32E-R2; ESP32-WROOM-32E
U2: MCP73831-2-OT; SOT-23-5
U3: AP2112K-3.3; SOT-23-5
U4: PCM5102A; TSSOP-20_4.4x6.5mm_P0.65mm
U5: PAM8908; QFN-16-1EP_3x3mm_P0.5mm_EP1.7x1.7mm
U6: BQ27441-G1; Texas_S-PDSO-N12
U7: USBLC6-2SC6; SOT-23-6
U8: CP2102N-A02-GQFN24; QFN-24-1EP_4x4mm_P0.5mm_EP2.6x2.6mm

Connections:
3V3: C5.1, C6.1, C9.1, C10.1, C12.1, C13.1, C14.1, C27.1, D1.4 (VDD), FB1.1, J2.4 (VDD), J4.2, J6.1, R7.1, R8.1, R9.1, R10.1, R11.1, R12.1, R13.1, R14.1, R15.1, R16.1, R17.1, R20.1, R25.1, R26.1, R27.1, R28.1, R29.1, R30.1, R33.1, U1.2 (VDD), U3.5 (VOUT), U4.20 (DVDD)
3V3A: C7.1, C8.1, C15.1, C16.1, C25.1, C26.1, FB1.2, U4.1 (CPVDD), U4.8 (AVDD), U5.14 (PVDD)
AMP_CAPM: C22.2, U5.9 (CAP-)
AMP_CAPP: C22.1, U5.11 (CAP+)
AMP_EN: R18.1, U1.26 (IO4), U5.13 (EN)
BTN_NEXT: R30.2, SW4.1, U1.5 (SENSOR_VN)
BTN_PLAY: R29.2, SW3.1, U1.4 (SENSOR_VP)
BTN_PREV: R28.2, SW2.1, U1.6 (IO34)
CC1: J1.A5 (CC1), R1.1
CC2: J1.B5 (CC2), R2.1
CHG_LED_A: D2.2 (A), R4.2
CHG_PROG: R3.1, U2.5 (PROG)
CHG_STAT: D2.1 (K), U2.1 (STAT)
CP_CAPM: C17.2, U4.4 (CAPM)
CP_CAPP: C17.1, U4.2 (CAPP)
CP_RSTN: R31.2, U8.9 (~RST)
CP_RXD: R32.2, U8.20 (RXD)
CP_VBSENSE: R34.2, R35.1, U8.8 (VBUS)
CP_VDD: C32.1, C34.1, C36.1, R31.1, U8.5 (VIO), U8.6 (VDD)
DAC_LDOO: C19.1, U4.18 (LDOO)
DAC_OUTL: C20.1, U4.6 (OUTL)
DAC_OUTR: C21.1, U4.7 (OUTR)
DAC_VNEG: C18.1, U4.5 (VNEG)
DAC_XSMT: R17.2, U1.13 (IO14), U4.17 (XSMT)
ENC_A: C30.1, R25.2, SW1.A, U1.8 (IO32)
ENC_B: C31.1, R26.2, SW1.B, U1.9 (IO33)
ENC_SW: R27.2, SW1.S1, U1.7 (IO35)
EN_LDO: SW7.3 (C), U3.3 (EN)
ESP_EN: C11.1, Q2.3 (C), R7.2, SW6.1, U1.3 (EN)
ESP_IO0: Q3.3 (C), R8.2, SW5.1, U1.25 (IO0)
FG_BAT: C29.1, R23.2, U6.6 (BAT)
FG_GPOUT: U6.12 (GPOUT)
FG_VDD: C28.1, U6.5 (V_{DD})
GATE_LS: Q1.1 (G), R5.2, R6.1
GND: C1.2, C2.2, C3.2, C4.2, C5.2, C6.2, C7.2, C8.2, C9.2, C10.2, C11.2, C12.2, C13.2, C14.2, C15.2, C16.2, C18.2, C19.2, C23.2, C24.2, C25.2, C26.2, C27.2, C28.2, C29.2, C30.2, C31.2, C32.2, C33.2, C34.2, C35.2, C36.2, D1.2 (VSS), J1.A1 (GND), J1.A12 (GND), J1.B1 (GND), J1.B12 (GND), J1.SH (SHIELD), J2.6 (VSS), J2.10 (DET_A), J2.SH (SHIELD), J3.S, J4.1, J6.4, R1.2, R2.2, R3.2, R6.2, R18.2, R24.2, R35.2, R38.2, SW1.C, SW1.MP, SW1.S2, SW2.2, SW3.2, SW4.2, SW5.2, SW6.2, SW7.2 (B), U1.1, U1.15, U1.38, U1.39, U1.[1,15,38,39] (GND), U2.2 (V_{SS}), U3.2 (GND), U4.3 (CPGND), U4.9 (AGND), U4.10 (DEMP), U4.11 (FLT), U4.12 (SCK), U4.16 (FMT), U4.19 (DGND), U5.1 (INL-), U5.4 (INR-), U5.6 (G0), U5.7 (G1), U5.10 (PGND), U5.15 (SGND), U5.17 (EPAD), U6.3 (V_{SS}), U6.7 (SRN), U6.10 (BIN), U6.13 (PAD), U7.2 (GND), U8.2 (GND), U8.18 (~CTS), U8.22 (~DSR), U8.24 (~DCD), U8.25 (GND)
HPVDD: C23.1, U5.12 (HPVDD)
HPVSS: C24.1, U5.8 (HPVSS)
HP_INL: C20.2, U5.2 (INL+)
HP_INR: C21.2, U5.3 (INR+)
HP_L: J3.T, U5.16 (OUTL)
HP_R: J3.R, U5.5 (OUTR)
I2C_SCL: J4.3, R10.2, U1.36 (IO22), U6.2 (SCL)
I2C_SDA: J4.4, R9.2, U1.33 (IO21), U6.1 (SDA)
I2S_BCK: U1.11 (IO26), U4.13 (BCK)
I2S_DIN: U1.12 (IO27), U4.14 (DIN)
I2S_LRCK: U1.10 (IO25), U4.15 (LRCK)
JACK_DET: R19.2, R20.2, U1.23 (IO15)
JACK_TN: J3.TN, R19.1
LED_DIN: D1.3 (DIN), R38.1, U1.24 (IO2)
PACK_NEG: J5.2, R24.1, U6.8 (SRP)
Q2_BASE: Q2.1 (B), R36.2
Q3_BASE: Q3.1 (B), R37.2
SD_CD: J2.9 (DET_B), R16.2, U1.16 (IO13)
SD_CS: J2.2 (DAT3/CD), R15.2, U1.29 (IO5)
SD_D1: J2.8 (DAT1), R13.2
SD_D2: J2.1 (DAT2), R14.2
SD_MISO: J2.7 (DAT0), R12.2, U1.31 (IO19)
SD_MOSI: J2.3 (CMD), R11.2, U1.37 (IO23)
SD_SCK: J2.5 (CLK), U1.30 (IO18)
UART_DTR: Q3.2 (E), R36.1, U8.23 (~DTR)
UART_RTS: Q2.2 (E), R37.1, U8.19 (~RTS)
UART_RX: J6.3, R33.2, U1.34 (RXD0/IO3), U8.21 (TXD)
UART_TX: J6.2, R32.1, U1.35 (TXD0/IO1)
USB_DM: J1.A7 (D-), J1.B7 (D-), U7.1 (I/O1), U7.6 (I/O1), U8.4 (D-)
USB_DP: J1.A6 (D+), J1.B6 (D+), U7.3 (I/O2), U7.4 (I/O2), U8.3 (D+)
VBAT: C3.1, J5.1, Q1.2 (S), R23.1, U2.3 (V_{BAT})
VBUS: C1.1, C2.1, C33.1, C35.1, D3.2 (A), J1.A4 (VBUS), J1.A9 (VBUS), J1.B4 (VBUS), J1.B9 (VBUS), R4.1, R5.1, R34.1, U2.4 (V_{DD}), U7.5 (VBUS), U8.7 (VREGIN)
VSYS: C4.1, D3.1 (K), Q1.3 (D), SW7.1 (A), U3.1 (VIN)

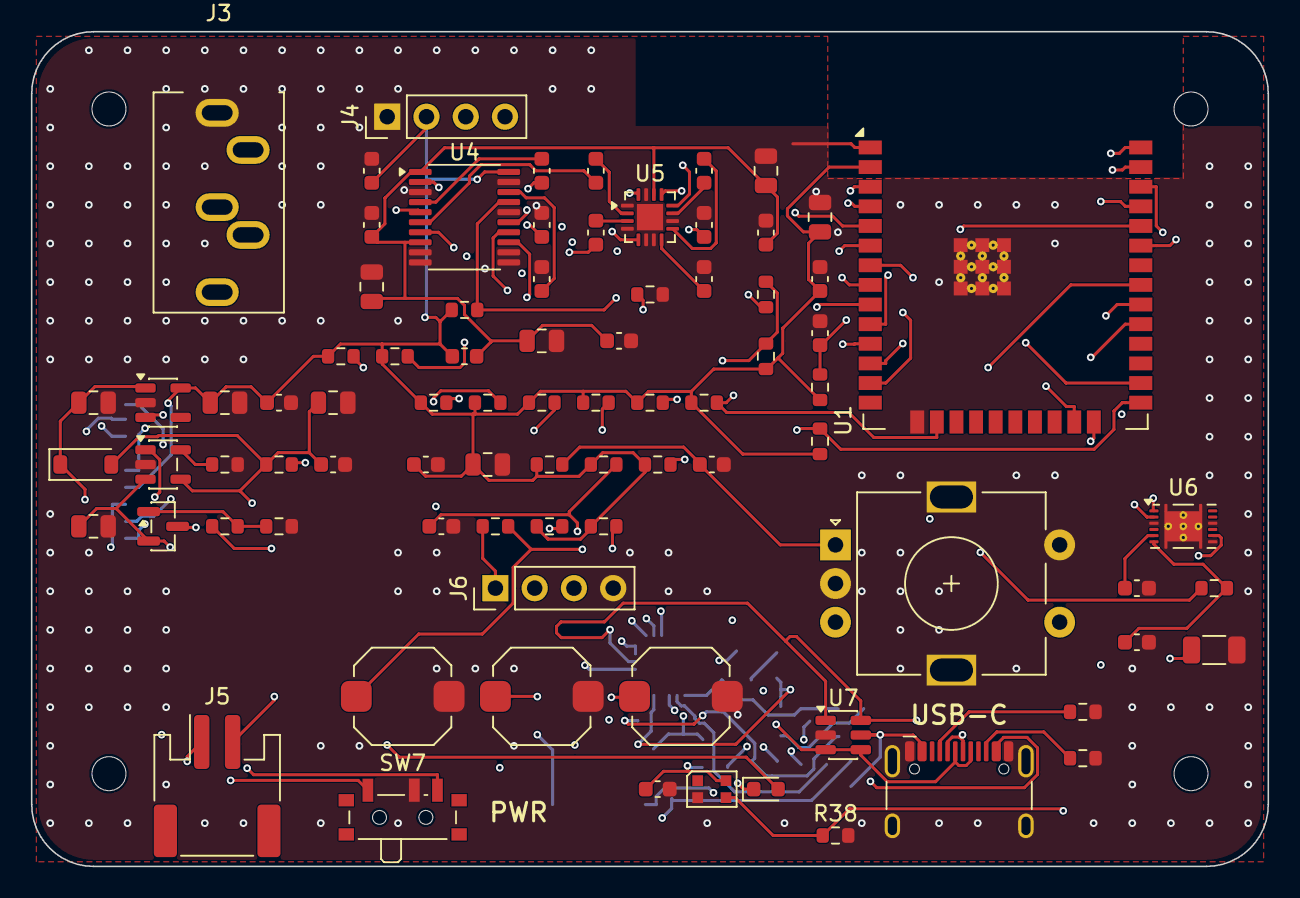
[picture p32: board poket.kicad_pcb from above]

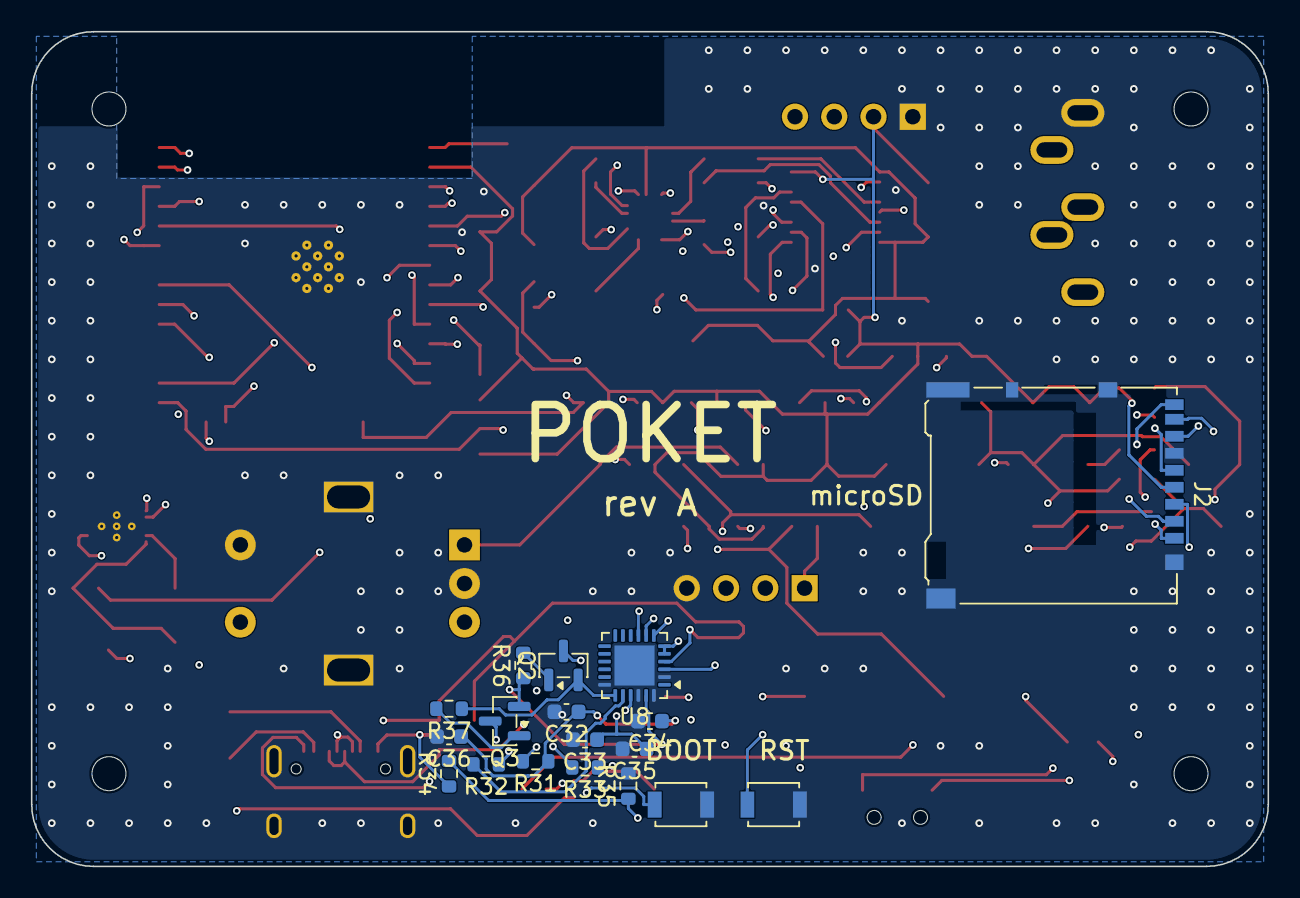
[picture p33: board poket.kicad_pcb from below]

Board: 4 copper layers, 80.0 x 54.0 mm, 104 parts (18 on the bottom side), 67 nets.

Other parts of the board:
MH1, MH2, MH3, MH4: MountingHole_2.2mm

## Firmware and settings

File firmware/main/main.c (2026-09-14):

// Poket - pocket Bluetooth MP3 player.
//
// Bring-up order matters: NVS first (the theme and the AP password live
// there), then the panel so a failure later has somewhere to be reported,
// then the card, then audio. The UI task starts before the library scan so
// the splash is up while a big card is being walked.
#include "app/app_state.h"
#include "app/ui_task.h"
#include "audio/player.h"
#include "board.h"
#include "drivers/battery.h"
#include "drivers/i2c_bus.h"
#include "drivers/input.h"
#include "drivers/ssd1306.h"
#include "storage/library.h"
#include "storage/sdcard.h"
#include "ui/theme.h"
#include "audio/bt_link.h"

#include "esp_log.h"
#include "esp_err.h"
#include "nvs_flash.h"
#include "freertos/FreeRTOS.h"
#include "freertos/task.h"

static const char *TAG = "poket";

static void scan_task(void *arg) {
    (void)arg;
    if (library_scan() == ESP_OK)
        ESP_LOGI(TAG, "library: %u tracks", library_count());
    else
        ESP_LOGW(TAG, "library scan failed");
    vTaskDelete(NULL);
}

void app_main(void) {
    ESP_LOGI(TAG, "Poket %s", POKET_FW_VERSION);

    esp_err_t err = nvs_flash_init();
    if (err == ESP_ERR_NVS_NO_FREE_PAGES || err == ESP_ERR_NVS_NEW_VERSION_FOUND) {
        ESP_ERROR_CHECK(nvs_flash_erase());
        err = nvs_flash_init();
    }
    ESP_ERROR_CHECK(err);

    app_state_init();
    ESP_ERROR_CHECK(i2c_bus_init());
    ESP_ERROR_CHECK(ssd1306_init());
    theme_init();                    // restores the saved choice, or minimal
    input_init();
    battery_init();
    ui_task_start();                 // splash is now on screen

    if (sdcard_mount() == ESP_OK) {
        // Walking a full card takes seconds; do it off the main task so the
        // splash keeps animating and the buttons stay live.
        xTaskCreate(scan_task, "scan", 4096, NULL, 3, NULL);
    } else {
        ESP_LOGE(TAG, "no card");
    }

    ESP_ERROR_CHECK(player_init());

    // If a headset was linked before, go straight back to it rather than
    // making the user pick from a scan on every boot.
    if (bt_link_has_saved()) {
        ESP_LOGI(TAG, "reconnecting to %s", bt_link_saved_name());
        bt_link_connect_saved();
    }
    ESP_LOGI(TAG, "ready");
}

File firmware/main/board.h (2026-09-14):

// Poket board pin map.
//
// Every number here was pulled out of poket.kicad_sch with
//   kicad-cli sch export netlist --format kicadxml
// rather than typed from memory. If the schematic moves, re-export and fix
// this file; nothing else in the firmware should hard-code a GPIO.
//
// REV B: the module changed from ESP32-S3-WROOM-1 to ESP32-WROOM-32E-R2.
// The S3 has Bluetooth LE only - no BR/EDR - so A2DP source, which is the
// whole point of "sends to Bluetooth headphones", could never have worked on
// it. The classic ESP32 in the -32E-R2 keeps its 2 MB PSRAM in-package, so
// unlike a WROVER it does not eat GPIO16/17 to get it.
#pragma once

#define POKET_FW_VERSION "0.2.0"
#include "driver/gpio.h"

// ---- rotary encoder (EC11, detented, with push) -------------------------
#define PIN_ENC_A        GPIO_NUM_32
#define PIN_ENC_B        GPIO_NUM_33
#define PIN_ENC_SW       GPIO_NUM_35     // input-only: needs the board's 10k

// ---- transport buttons, all active low ---------------------------------
// GPIO34/36/39 are input-only and have NO internal pull-ups, so R20-R22 on
// the board are not optional the way they were on the S3.
#define PIN_BTN_PREV     GPIO_NUM_34
#define PIN_BTN_PLAY     GPIO_NUM_36
#define PIN_BTN_NEXT     GPIO_NUM_39

// ---- I2S to the PCM5102A -----------------------------------------------
// No MCLK line exists: the DAC runs off its internal PLL from BCK/LRCK.
// Configuring an MCLK pin here would be a silent bug - there is no trace.
#define PIN_I2S_BCK      GPIO_NUM_26
#define PIN_I2S_LRCK     GPIO_NUM_25
#define PIN_I2S_DIN      GPIO_NUM_27
#define PIN_DAC_XSMT     GPIO_NUM_14     // soft mute, high = unmuted

// ---- I2C: SSD1306 OLED + BQ27441 fuel gauge ----------------------------
#define PIN_I2C_SDA      GPIO_NUM_21
#define PIN_I2C_SCL      GPIO_NUM_22
#define I2C_ADDR_OLED    0x3C
#define I2C_ADDR_GAUGE   0x55

// ---- microSD over SPI ---------------------------------------------------
// NOT the SDMMC peripheral. On the classic ESP32, slot 1 is hard-wired to
// GPIO12 for DAT2, and GPIO12 is MTDI - the flash voltage strap. A microSD
// card's internal pull-up on DAT2 holds it high at reset, which tells the
// bootloader the flash is 1.8 V and bricks the boot. SPI costs bandwidth
// nobody here needs: 320 kbps audio is 40 kB/s and the Wi-Fi link is the
// bottleneck on uploads regardless.
#define PIN_SD_SCK       GPIO_NUM_18
#define PIN_SD_MISO      GPIO_NUM_19
#define PIN_SD_MOSI      GPIO_NUM_23
#define PIN_SD_CS        GPIO_NUM_5
#define PIN_SD_CD        GPIO_NUM_13     // low = card present
#define SD_SPI_HOST      SPI2_HOST       // HSPI
#define SD_SPI_HZ        (20 * 1000 * 1000)

// ---- misc ---------------------------------------------------------------
#define PIN_AMP_EN       GPIO_NUM_4      // PAM8908 enable, high = on
#define PIN_JACK_DET     GPIO_NUM_15     // low = plug inserted
#define PIN_LED_DIN      GPIO_NUM_2      // WS2812B-2020, single pixel

// Strapping pins and what this board does about them:
//   GPIO0  BOOT button, pulled up. Also driven by the CP2102N auto-reset pair.
//   GPIO2  WS2812 data. Idles low, which is what the strap wants. Safe.
//   GPIO12 MTDI / flash voltage. LEFT UNCONNECTED - see the microSD note.
//   GPIO15 MTDO / boot-log enable, internal pull-up. Jack detect pulls it low
//          when a plug is in, so booting with headphones plugged in is silent
//          on U0TXD. Cosmetic only.
// GPIO6-11 are the module's SPI flash and are not brought out.
// There is no battery-sense divider: ADC1 is fully consumed by the encoder
// and buttons, and the BQ27441 reports voltage and current over I2C anyway.

#define BATT_FULL_MV         4200
#define BATT_EMPTY_MV        3300

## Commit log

2026-09-09 Schematic: full Poket design, ERC clean
    ESP32-S3-WROOM-1 core, PCM5102A I2S DAC into PAM8908 headphone amp,
    microSD on 4-bit SDIO, MCP73831 charger with P-FET load share,
    BQ27441 fuel gauge, AP2112K 3V3 rail, OLED + EC11 + 3 buttons.
    [poket-bom.csv, poket.kicad_pcb, poket.kicad_sch]
2026-09-10 PCB placement + parametric FreeCAD enclosure
    80x54mm 4-layer board, all 90 footprints placed, GND pours on all four
    layers with an antenna notch. Enclosure built headless in FreeCAD:
    two shells plus slider cap, STEP + STL exported.
    [_test.step, poket-back-shell.step, poket-back-shell.stl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]
2026-09-10 Add README
    [poket.dsn]
2026-09-10 Route PCB, 0 DRC errors
    Freerouting at 0.2mm track / 0.15mm clearance, GND pours on all four
    layers with an antenna notch, 215 stitching vias, silkscreen cleaned up.
    DRC: 0 errors, 0 unconnected, 0 schematic parity issues.
    [poket-B_Adhesive.gbr, poket-B_Courtyard.gbr, poket-B_Cu.gbr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]
2026-09-10 Re-route with In1.Cu as a solid ground plane
    Marked In1.Cu as a power layer in the DSN so freerouting leaves it alone;
    it now carries no signal copper. Regenerated gerbers, drill, pick-and-place,
    BOM and renders. DRC: 0 errors, 0 unconnected, 0 parity.
    [poket-B_Adhesive.gbr, poket-B_Courtyard.gbr, poket-B_Cu.gbr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]
2026-09-10 Add PCB/enclosure fit check, final journal entry
2026-09-10 Rebuild enclosure in FreeCAD GUI session
    Fixes the slider cap, which the headless build had left as four
    disconnected solids. Lighter board STEP, finer STL tessellation,
    assembly STEP without the board, real GUI renders. Interference against
    the KiCad board model is now zero everywhere.
    [_test.step, poket-back-shell.step, poket-back-shell.stl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]
2026-09-10 Add Blender assembly animation
    Exploded-to-assembled build plus a turntable, 194 frames at 1280x720/30fps.
    Parts come from the FreeCAD STL exports; the board is the KiCad orthographic
    renders projected on in object space, split top/bottom by surface normal.
    Scene is reproducible from blender/build_scene.py.
    [back-shell.stl, front-shell.stl, pcb.stl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]
2026-09-10 Document the assembly animation
2026-09-10 Straight chamfered edges, promo film, BOM and submission docs
    Enclosure: replaced every fillet with a 45 deg chamfer - 1.2 mm on the outer
    vertical corners, 0.8 mm on the top and bottom rims. Rebuilt, re-exported,
    re-rendered; still zero interference against the board.
    Blender: build_scene.py now rebuilds either the 6.5 s assembly clip or the
    22 s five-shot promo from the STLs alone, so losing the .blend costs nothing.
    Adds a lit-screen emitter and camera-bound shot markers.
    Docs: BOM (98 parts, ~$46/unit, estimates flagged as estimates), assembly
    guide, submission checklist with the real gaps, MIT + CERN-OHL-S license.
    [BOM.csv, back-shell.stl, front-shell.stl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]
2026-09-10 Journal: edges, promo, BOM
2026-09-10 Ignore promo frame sequence
2026-09-11 Studio hero render and product ad
    Second Blender look, separate from the assembly/promo scene: deep blue
    vertical gradient, product floating with no floor, long lenses and shallow
    depth of field, cut between a wide establishing shot and four macro details.
    24 s at 1280x720.
    Also a portrait hero still of two units, one leaning on the other, on a dark
    navy gradient with a soft floor reflection.
    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
    [poket-ad.blend, poket.blend]
2026-09-11 Hero still: translucent shells, engraved wordmark, button caps, Cycles GPU
    Shells are now transmissive with a volume-absorption tint so the board reads
    through the case. 'Poket' is cut into the front shell with a boolean and an
    inlay joined into the same object - a bare engraving in clear plastic renders
    as nothing. Button caps and an encoder knob fill the holes. Both units float,
    posed after the cassette reference. Cycles on OptiX, 320 samples.
    blender/build_hero.py rebuilds the whole scene from the STLs.
    [poket-hero.blend, poket.blend]
2026-09-11 Shot-for-shot remake of the reference film
    Cut list taken from the source with ffmpeg scene detection: 13 CG shots over
    34.36 s at 25 fps, same durations and rhythm. The final 10.9 s of the source is
    live action and is not reproduced.
    Macro cameras are parented to the unit so they survive its rotation, and the
    pose is keyed per cut rather than one continuous tumble - a single tumble left
    every macro aiming at empty space.
    [poket-hero.blend, poket-remake.blend, poket.blend]
2026-09-13 Firmware: drivers, audio path, six OLED themes, web UI prototypes
    ESP-IDF v5.3 app for the ESP32-S3. Pin map extracted from the schematic
    netlist so it can't drift from the board.
    - drivers: I2C bus, SSD1306, encoder + buttons, BQ27441 fuel gauge
    - storage: SDMMC 4-bit mount, library scan, ID3 tags
    - audio: vendored minimp3, one sink interface behind I2S and A2DP source
    - ui: 1-bit framebuffer and a theme engine; six themes that differ in
    layout, type, iconography and motion, not palette (the panel has none)
    - custom themes are data, not code, so an uploaded pack cannot execute
    Font pipeline, three real bugs fixed:
    - librsvg ignores @font-face src:url(), so all nine "faces" were the same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
    [partitions.csv, poket-remake.blend]
2026-09-14 Rev B: swap to ESP32-WROOM-32E-R2 so Bluetooth audio actually works
    The ESP32-S3 has Bluetooth LE only - no BR/EDR - so A2DP source, the whole
    point of "sends to Bluetooth headphones", could never have worked on it.
    ESP-IDF's own soc_caps.h is explicit: esp32 defines SOC_BT_CLASSIC_SUPPORTED,
    esp32s3 does not, and CONFIG_BT_CLASSIC_ENABLED is not even a symbol there.
    New MCU: ESP32-WROOM-32E-N16R2 (ESP32-D0WDR2-V3, Classic BT + BLE, 16 MB
    flash, 2 MB PSRAM in the chip package so GPIO16/17 stay free unlike a WROVER).
    Knock-on changes, all verified against datasheets:
    - CP2102N-A02-GQFN24 USB-UART bridge; this part has no native USB.
    VBUS sense gets the datasheet's required 22.1k/47.5k div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
    [BOM.csv, poket-back-shell.step, poket-enclosure-assembly.step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]
2026-09-14 Bluetooth: actually link to headphones, not just initialise A2DP
    The old code brought up the A2DP source and then made Poket *discoverable*,
    which is what a speaker does. A source has to go the other way: run an
    inquiry, pick out the audio sinks, and page one. Nothing was ever going to
    connect to us, so the Bluetooth output was dead even on hardware that
    supports it.
    Implemented per ESP-IDF's own a2dp_source example:
    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
2026-09-14 Web app: a Bluetooth panel that actually pairs
    The endpoints existed but nothing called them, so linking a headset meant
    hitting URLs by hand. The side column now carries a Bluetooth block:
    - Scan runs an 8 s inquiry and follows the device until it reports the scan
    stopped, rather than guessing at a fixed delay
    - Found headsets list with name, address and signal strength drawn as bars;
    "-68 dBm" tells someone picking their headphones out of a list nothing
    - Tap to link, then Disconnect / Forget once a link is up
    - The remembered headset shows as "will reconnect automatically", so the
    normal case needs no interaction at all
    Failures are surfaced instead of swallowed. send() deliberate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
2026-09-14 Playlists, search and a clock that was lying; regenerate everything for Rev B
    Playback position advanced one second every 25 animation frames, which assumes
    a 25 Hz display. At 60 Hz the clock ran 2.4x fast - a four minute track ran out
    in a hundred seconds. Position is time, so it is now kept as "elapsed E as of
    wall-time T" and interpolated.
    The arithmetic moved to lib/clock.js with a node test, and that mattered:
    verifying it through headless Chrome measured 0.800x and I nearly "fixed" a
    clock that was already right. Virtual time throttles requestAnimationFrame, so
    that test was measuring repaint cadence, not the clock. Against a fake time
    source it is exact - pause holds, resume continu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
    [poket-B_Adhesive.gbr, poket-B_Courtyard.gbr, poket-B_Cu.gbr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]
2026-09-14 Journal: image for the MCU-swap entry, and untangle the schematic fields
    The Sep 14 entry about dropping the ESP32-S3 had no image. It does now: a crop
    of the USB bridge block, which is the part of the board that entry is actually
    about - CP2102N, the VBUS sense divider, the RSTb pull-up, a bypass pair per
    power pin, and the cross-coupled auto-reset transistors.
    Making that crop readable exposed a real defect. I placed those sixteen parts
    programmatically and never positioned their reference and value fields, so the
    designators, values and net labels were stacked on top of each other - in the
    crop, and in docs/poket-schematic.pdf that anyone reviewing this would read.
    Moved the fields clear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
    [poket.kicad_sch]
